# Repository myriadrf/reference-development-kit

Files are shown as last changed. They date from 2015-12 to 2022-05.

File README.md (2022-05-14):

# Myriad-RF Hardware

This repository contains the [Myriad-RF](http://myriadrf.org/) reference hardware designs for Lime Microsystem's LMS6002D and LMS7002M transceivers, plus LMS8001 up/down converter, in PDF and [KiCad](http://www.kicad.org) formats, along with the associated firmware.

## Contents

The directory structure for the hardware designs is as follows:

      docs/                      - platform documentation

      <project>/hardware/<version>/
          BOM/                   - bill of materials spreadsheet
          Gerbers/               - Gerber CAM files
          KiCAD/                 - KiCAD schematic and layout files
          Manufacturing/         - Additional manufacturing information
          PDF/                   - Schematic and layout PDFs
          Reports/               - DRC, ERC and drill reports

### Documentation

* RFDIO Connector Specification

The Myriad-RF Radio Frequency Digital Input Output (RFDIO) connector specification defines the electrical and mechanical properties of a high speed card interface for Field Programmable Gate Array (FPGA) based carrier boards. This specification ensures interoperability between carrier (mother) boards and add-on (daughter) RF cards.

*Please note that this needs to be updated with details of the connector specification used by the micro series of boards.*

### Myriad-RF 1 module (myriadrf-1)

Hardware design files for the LMS6002-based Myriad-RF 1 RF module.

Note that there are two versions of the design: one with vias in pads, and another with them off.

### DE0-Nano Interface (de0nano-interface)

Hardware design files and firmware sources (FPGA HDL + Cypress FX2 code) for the DE0-Nano interface that is used with the original Myriad-RF 1 module.

### Zipper Interface (zipper)

This interface allows the Myriad-RF 1 to be used with FPGA development boards that have either a HSMC or FMC connector.

*Note that v1 of the hardware design was not made generally available.*

### uMyriadRF-6002 (umyriadrf-6002)

LMS6002 version of the micro form factor RF module.

### uMyriadRF-7002 (umyriadrf-7002)

LMS7002 version of the micro form factor RF module.

### MyriadRF-8001 (myriadrf-8001)

LMS8001 Companion.

## Licensing

### Hardware

The hardware designs are licensed under a Creative Commons Attribution 3.0 Unported licence.

*Note: The Myriad-RF 1 and DE0-Nano Interface hardware designs were initially published under the Creative Commons Attribution-ShareAlike 3.0 Unported licence. As of 30th September 2013 these have been re-licensed under the more permissive Creative Commons Attribution 3.0 Unported licence.*

### Firmware

For details of firmware licensing please see the associated COPYING file(s).

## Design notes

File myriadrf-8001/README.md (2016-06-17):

# LMS8001 Companion

## Front

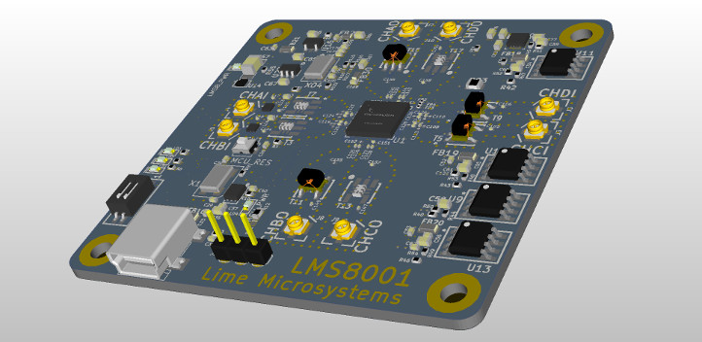
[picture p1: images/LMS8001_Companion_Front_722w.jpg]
LMS8001 Companion front


## Back

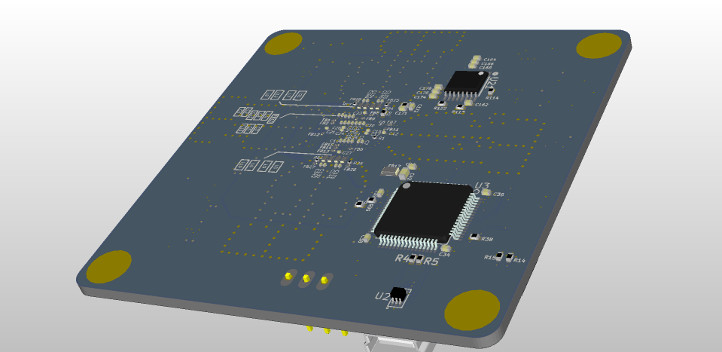
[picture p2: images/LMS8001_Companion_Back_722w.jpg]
LMS8001 Companion back


## Specifications

* Frequency range: 100kHz – 12GHz
* RF bandwidth: 120 MHz
* TRX configuration: MIMO
* Duplex: Full and half
* Power consumption: 1.5W

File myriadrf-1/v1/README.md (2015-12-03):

# Myriad-RF 1 RF Module version 1

## IMPORTANT!

Previous versions are retained for reference and are not intended for use in manufacturing.

## Changes

Note that r1 and r2 were interim updates and were not manufactured.

### 2014-03-03 r.3

Updated due to obsolete components.

Changed:

#### Schematics updates, pages "Clocks” and  “RF FE":

1. Component DA6 - Obsolete RF switch (PE4210) is changed, to new part PE42422
2. Added capacitor on TX Test track C26=100pF

#### PCB Layout updates

1. New footprint of PE42422 part
2. Rounded RF tracks
3. The GND and power supply vias mask closed (so there is no open vias on board)
4. The board annotation note "Board v.1 r.3" on the bottom layer silkscreen
5. The dimension lines (48 x 46 mm) on Drawings layer

#### BOM updates

1. Manufacturer of the capacitors is to KEMET: Capacitor values: 1.2pF, 1.8pF and 3.9pF
2. Included Board revision line
3. Changed dimensions to 48 x 46 mm
4. Included Drawings layout in list of gerber files
5. Included more report files in report folder

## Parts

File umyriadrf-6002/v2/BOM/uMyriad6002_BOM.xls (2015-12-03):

Component | QTY | Reference | Footprint | Supplier | Supplier Part Nr | Manufacturer | Manu Part Nr | Description | Assemble
1.0pF | 1 | C4 | C_SM0402 | Farnell | 1889196 | MURATA | GJM1555C1H1R0BB01D | CAPACITOR; NP0; 0402; 1PF;
8.2pF | 2 | C6 C8 | C_SM0402 | Farnell | 1865418 | KEMET | C0402C829C5GACTU | CAPACITOR; NP0; 0402; 50V; 8.2PF;
10pF | 1 | C22 | C_SM0402 | Farnell | 1709776 | MULTICOMP | MC0402N100F500CT | CAPACITOR CERAMIC 10PF 50V; C0G; 1%; 0402
33pF | 14 | C17 C37 C39 C42 C46 C48 C50 C51 C54 C56 C57 C61 C63 C65 | C_SM0402 | Farnell | 1856052 | MULTICOMP | MCCA000902 | CAPACITOR; 0402; NP0; 16V; 33PF;
100pF | 4 | C2 C3 C5 C7 | C_SM0402 | Farnell | 8819572 | MURATA | GRM1555C1H101JD01D | CAPACITOR; 0402; 100PF; 50V;
150pF | 2 | C11 C14 | C_SM0402 | Farnell | 1758976 | MULTICOMP | MCCA000122 | MLCC; 0402; NP0; 50V; 150PF;
470pF | 2 | C9 C12 | C_SM0402 | Farnell | 1758987 | MULTICOMP | MCCA000132 | MLCC; 0402; X7R; 50V; 470PF;
10nF | 2 | C10 C13 | C_SM0402 | Farnell | 3019275 | YAGEO (PHYCOMP) | CC0402KRX7R7BB103 | CAPACITOR; 0402; 10NF; 16V;
100nF | 17 | C1 C15 C16 C36 C38 C40 C41 C43 C45 C47 C49 C53 C55 C59 C62 C67 C111 | C_SM0402 | Farnell | 1288282 | KEMET | C0402C104K8PACTU | CAPACITOR; 0402; 100NF; 10V; X5R;
1uF | 5 | C60 C66 C68 C69 C204 | C_SM0402 | Farnell | 1759381 | MULTICOMP | MCCA000506 | MLCC; 0402; X5R; 10V; 1UF;
10uF | 2 | C52 C58 | C_SM0603 | Farnell | 2113070RL | TAIYO YUDEN | LMK107BJ106MALTD | CAPACITOR; 10UF; 10V; X5R; 0603;
LMS6002DR2 | 1 | DA1 | ~
SHIELD | 1 | EK1 | shield_21x21mm | Digi-Key | 732-2486-ND | Wurth Electronics Inc | 36103205 | BOARD SHIELD 20X20MM SMD FRAME
SHIELD | 1 | EK2 | shield_21x21mm | Digi-Key | 732-2486-ND | Wurth Electronics Inc | 36103205 | BOARD SHIELD 20X20MM SMD FRAME | NOFIT
100-PIN_CONNECTOR_1.5MMHEIGHT | 1 | J1 | 100-PIN_CONNECTOR | Digi-Key | H11615CT-ND | Hirose Electric Co Ltd | DF40C-100DS-0.4V(51) | CONN RCPT 100POS 0.4MM SMD GOLD
12nH NF | 1 | L3 | L_SM0402 | Coilcraft | 0402HP-12NX_LU | Coilcraft | 0402HP-12NX_LU | Inductor, 12 nH, 0402, 5%, | NOFIT
36nH | 2 | L1 L2 | L_SM0402 | Coilcraft | 0402CS-36NX_LU | Coilcraft | 0402CS-36NX_LU | Inductor; 36 nH; 0402; 5%;
LED | 1 | LD1 | LD0603 | Farnell | 1226372RL | OSRAM | LGQ971 | OSRAM - LGQ971 - LED; SMD; GREEN;
0R_0402 | 2 | R55 R63 | R_SM0402 | Digi-Key | 311-0.0JRCT-ND | Yageo | RC0402JR-070RL | RES, 0.0 OHM,1/16W, JUMP, 0402 SMD,
22 | 2 | R53 R57 | R_SM0402 | Farnell | 1117301 | YAGEO (PHYCOMP) | RC0402FR-0722RL | RESISTOR; 0402; 22R; 1%; REEL 10000;
47 | 4 | R22 R23 R24 R25 | R_SM0402 | Farnell | 1117311 | YAGEO (PHYCOMP) | RC0402FR-0747RL | RESISTOR; 0402; 47R; 1%; REEL 10000;
390 | 1 | R7 | R_SM0402 | Farnell | 9239189 | YAGEO (PHYCOMP) | RC0402FR-07390RL | RESISTOR; RC32H; 0402; 390R;
470 | 1 | R35 | R_SM0402 | Farnell | 9239197 | YAGEO (PHYCOMP) | RC0402FR-07470RL | RESISTOR; RC32H; 0402; 470R;
820 | 2 | R2 R5 | R_SM0402 | Farnell | 1358040RL | MULTICOMP | MC 0.0625W 0402 1% 820R | RESISTOR; 0402; 1%; 820R;
1K2 | 2 | R1 R3 | R_SM0402 | Farnell | 1358045 | MULTICOMP | MC 0.0625W 0402 1% 1K2 | RESISTOR; 0402; 1%; 1K2;
6K8 | 1 | R6 | R_SM0402 | Farnell | 1358064 | MULTICOMP | MC 0.0625W 0402 1% 6K8 | RESISTOR; 0402; 1%; 6K8;
10K_0402 | 3 | R11 R17 R21 | R_SM0402 | Digi-Key | 311-10.0KLRCT-ND | Yageo | RC0402FR-0710KL | RES 10K OHM 1/16W 1% 0402 SMD
12K | 1 | R4 | R_SM0402 | Farnell | 1358071RL | MULTICOMP | MC 0.0625W 0402 1% 12K | RESISTOR; 0402; 1%; 12K;
100MHz/600/0.2A | 15 | R41 R42 R43 R44 R46 R48 R50 R51 R52 R54 R56 R59 R60 R61 R62 | R_SM0402 | Farnell | 1961693 | WURTH ELEKTRONIK | 7427927161 | FERRITE BEAD; 600R; 0.25A; 0402;
SCREW | 1 | S1 | SCREW
TR_TCM1-63AX+ | 2 | T1 T2 | TCM1-63AX+ | Mini-Circuits | RF Transformer; 10 - 6000 MHz; RF Power 0.2 Watt; Ratio 1:1; 50 Ohm; | TCM1-63AX+ | TCM1-63AX+ | TCM1-63AX+
U.FL | 2 | X1 X2 | U.FL | Digi-Key | WM5587CT-ND | Molex Inc | 734120110 | CONN UMC RCPT STR 50 OHM SMD

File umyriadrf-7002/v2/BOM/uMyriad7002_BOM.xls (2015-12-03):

Component | QTY | Referene | Footprint | Supplier | Supplier Part Nr | Manufacturer | Manu Part Nr | Description | Assemble
0.5PF_0402_NF | 2 | C6 C41 | SMD0402 | DigiKey | 311-1001-1-ND | Yageo | CC0402CRNPO9BNR50 | CAP CER, 0.5PF, 50V, NPO, 0402, | NOFIT
4.7PF_0402 | 4 | C9 C10 C11 C12 | SMD0402 | DigiKey | 490-6244-1-ND | Murata Electronics North America | GRM1555C1H4R7BA01D | CAP CER 4.7PF 50V NP0 0402
1UF_0201 | 46 | C35 C47 C50 C51 C52 C53 C54 C55 C56 C57 C58 C59 C60 C61 C62 C63 C65 C66 C67 C68 C69 C111 C145 C154 C167 C173 C175 C195 C197 C204 C205 C206 C207 C208 C209 C210 C211 C212 C213 C214 C255 C283 C301 C302 C303 C304 | SM0201 | Digi-Key | 445-8008-1-ND | TDK Corporation | C0603X5R0J105M030BC | CAP CER 1UF 6.3V 20% X5R 0201
100NF_0402 | 10 | C1 C2 C16 C18 C38 C39 C220 C221 C233 C234 | SMD0402 | DigiKey | 311-1047-1-ND | Yageo | CC0402ZRY5V7BB104 | CAP, CER, 0.1UF, 16V, Y5V, 0402,
1PF_0402 | 6 | C3 C7 C32 C40 C42 C43 | SMD0402 | DigiKey | 445-4854-1-ND | TDK Corporation | C1005C0G1H010B050BA | CAP CER, 1PF, 50V, NP0, 0402,
1UF_0402 | 5 | C4 C8 C13 C14 C15 | SMD0402 | Digi-Key | 311-1377-1-ND | Yageo | CC0402ZRY5V5BB105 | CAP, CER, 1UF, 6.3V, Y5V, 0402,
10PF_0402 | 1 | C22 | SMD0402 | Digi-Key | 311-1014-1-ND | Yageo | CC0402JRNPO9BN100 | CAP, CER, 10PF, 50V, 5%, NPO, 0402,
100PF_0402 | 8 | C33 C45 C218 C219 C223 C231 C232 C236 | SMD0402 | Digi-Key | 311-1024-1-ND | Yageo | CC0402JRNPO9BN101 | CAP CER, 100PF, 50V, 5%, NPO, 0402,
22PF_0402 | 4 | C17 C19 C222 C235 | SMD0402 | DigiKey | 311-1018-1-ND | Yageo | CC0402JRNPO9BN220 | CAP CER, 22PF, 50V, 5%, NPO, 0402,
SHIELD_30X25MM | 1 | EK1 | shield_30x25mm
SHIELD_30X25MM | 1 | EK2 | shield_30x25mm |  |  |  |  |  | NOFIT
FB_0201 | 21 | FB1 FB2 FB3 FB4 FB5 FB6 FB7 FB8 FB9 FB10 FB11 FB12 FB13 FB14 FB15 FB16 FB17 FB18 FB19 FB22 FB24 | SM0201 | Digi-Key | 587-3277-1-ND | Taiyo Yuden | BK0603TS601-T | FERRITE BEAD 600 OHM 0201
FB_0201_NF | 2 | FB23 FB25 | SM0201 | Digi-Key | 587-3277-1-ND | Taiyo Yuden | BK0603TS601-T | FERRITE BEAD 600 OHM 0201 | NOFIT
100-PIN_CONNECTOR_3MMHEIGHT | 1 | J1 | 100-PIN_CONNECTOR | Digi-Key | H124602CT-ND | Hirose Electric Co Ltd | DF40HC(3.0)-100DS-0.4V(58) | CONN RCPT 100POS 0.4MM SMD GOLD
3.9NH_0402 | 2 | L4 L6 | IND_0402 | Coilcraft | 0402HP-3N9XGLU | Coilcraft | 0402HP-3N9XGLU | Inductor, 3.9 nH, 0402, 2%,
8.2NH_0402 | 4 | L7 L8 L12 L13 | IND_0402 | Coilcraft | 0402HP-8N2XJLU | Coilcraft | 0402HP-8N2XJLU | Inductor, 8.2 nH, 0402, 5%,
12NH_0402_NF | 4 | L3 L5 L9 L14 | IND_0402 | Coilcraft | 0402HP-12NX_LU | Coilcraft | 0402HP-12NX_LU | Inductor, 12 nH, 0402, 5%, | NOFIT
LED | 1 | LD1 | LED_0603 | Digi-Key | 475-1409-1-ND | OSRAM Opto Semiconductors Inc | LG Q971-KN-1 | LED, CHIPLED, 570NM, GREEN, 0603, SMD,
0R_0201 | 4 | R5 R6 R40 R43 | SMD0201 | Digi-Key | RHM0.0CCCT-ND | Rohm Semiconductor | MCR006YRTJ000 | RES 0.0 OHM 1/20W JUMP 0201 SMD
0R_0402 | 1 | R8 | SMD0402 | Digi-Key | 311-0.0JRCT-ND | Yageo | RC0402JR-070RL | RES, 0.0 OHM,1/16W, JUMP, 0402 SMD,
0R_0805 | 4 | R9 R12 R13 R14 | SM0805 | Digi-Key | 311-0.0ARCT-ND | Yageo | RC0805JR-070RL | RES SMD 0.0 OHM JUMPER 1/8W 0805
0.22R_0402 | 2 | R3 R4 | SMD0402 | Digi-Key | 311-.22PCT-ND | Yageo | RL0402FR-070R22L | RES SMD, 0.22 OHM, 1%, 1/16W, 0402,
10R_0201 | 6 | R7 R17 R23 R33 R41 R42 | SMD0201 | Digi-Key | YAG1245CT-ND | Yageo | RC0201JR-0710RP | RES SMD, 10 OHM, 5%, 1/20W, 0201,
47R_0402 | 4 | R25 R26 R27 R28 | SMD0402 | Digi-Key | 311-47.0LRCT-ND | Yageo | RC0402FR-0747RL | RES, 47 OHM, 1/16W, 1%, 0402, SMD,
470R_0402 | 1 | R10 | SMD0402 | Digi-Key | P470DECT-ND | Panasonic Electronic Components | ERA-2AED471X | RES, 470 OHM, 1/16W, .5%, 0402 SMD,
2K2_0402 | 2 | R29 R39 | SMD0402 | Digi-Key | 311-2.20KLRCT-ND | Yageo | RC0402FR-072K2L | RES, 2.20K OHM, 1/16W, 1%, 0402, SMD,
10K_0402 | 10 | R1 R2 R11 R19 R20 R21 R22 R24 R44 R45 | SMD0402 | Digi-Key | RMCF0402FT10K0CT-ND | Stackpole Electronics Inc | RMCF0402FT10K0 | RES 10K OHM 1/16W 1% 0402
TR_TC1 | 2 | T5 T6 | TC1-1-13MA+ | Municom | TC1-1-13MA+ | Mini-Circuits | TC1-1-13MA+ | RF Transformer, 4.5 - 3000 MHz, RF Power 0.25 Watt, Ratio 1:1, 50 Ohm,
TR_TCM1-63AX+ | 4 | T1 T2 T3 T4 | TCM1-63AX+ | Mini-Circuits | RF Transformer; 10 - 6000 MHz; RF Power 0.2 Watt; Ratio 1:1; 50 Ohm; | TCM1-63AX+ | TCM1-63AX+ | TCM1-63AX+
PE4245 | 2 | U7 U9 | 6-DFN_PE4245 | Digi-Key | 1046-1024-1-ND | Peregrine Semiconductor | 4245-52 | IC RF SWITCH SPDT 50 OHM 6-DFN
LD39115J14R | 1 | U2 | 4-UFBGA | Digi-Key | 497-15591-1-ND | STMicroelectronics | LD39115J14R | IC REG LDO 1.4V 0.15A 4FLIPCHIP
24FC512 | 1 | U6 | 8-TSSOP | Digi-Key | 24FC512-I/ST-ND | Microchip Technology | 24FC512-I/ST | IC EEPROM 512KBIT 1MHZ 8TSSOP
24FC64F | 1 | U8 | 8-TSSOP | Digi-Key | 24FC64F-I/ST-ND | Microchip Technology | 24FC64F-I/ST | IC EEPROM 64KBIT 1MHZ 8TSSOP
LMS7002 | 1 | U1 | aQFN-261
U.FL | 4 | X1 X2 X3 X4 | U.FL | Digi-Key | WM5587CT-ND | Molex Inc | 734120110 | CONN UMC RCPT STR 50 OHM SMD

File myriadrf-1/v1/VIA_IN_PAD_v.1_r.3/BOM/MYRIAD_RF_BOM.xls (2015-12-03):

VALUE | QTY | Reference | Footprint | Description | Manufacturer Part Number | Manufacturer | Vendor | Vendor Part Number | Assemble
0.5pF | 2 | C33 C120 | C_SM0402 | CAP; CER; 0.5PF; 50V; NPO; 0402; | CC0402CRNPO9BNR50 | Yageo | Digi-Key | 311-1001-2-ND
1.0pF | 3 | C21 C34 C72 | C_SM0402 | CAPACITOR; NP0; 0402; 1PF; | GJM1555C1H1R0BB01D | MURATA | Farnell | 1889196
1.2pF | 3 | C36 C44 C49 | C_SM0402 | CAP; CER; 1.2PF; 100V; NP0; 0402; | CBR04C129B1GAC | KEMET | Digi-Key | 399-8598-1-ND
1.8pF | 3 | C91 C92 C93 | C_SM0402 | CAP; CER; 1.8PF; 100V; NP0; 0402; | CBR04C189B1GAC | KEMET | Digi-Key | 399-8596-1-ND
3.9pF | 2 | C94 C95 | C_SM0402 | CAP; CER; 3.9PF; 100V; NP0; 0402; | CBR04C399B1GAC | KEMET | Digi-Key | 399-8588-1-ND
8.2pF | 2 | C31 C68 | C_SM0402 | CAPACITOR; NP0; 0402; 50V; 8.2PF; | C0402C829C5GACTU | KEMET | Farnell | 1865418
10pF | 1 | C221 | C_SM0402 | CAPACITOR CERAMIC 10PF 50V; C0G; 1%; 0402 | MC0402N100F500CT | MULTICOMP | Farnell | 1709776
33pF | 13 | C53 C55 C73 C78 C105 C106 C109 C110 C111 C112 C113 C114 C115 | C_SM0402 | CAPACITOR; 0402; NP0; 16V; 33PF; | MCCA000902 | MULTICOMP | Farnell | 1856052
100pF | 13 | C26 C27 C51 C54 C56 C57 C59 C60 C61 C63 C69 C77 C101 | C_SM0402 | CAPACITOR; 0402; 100PF; 50V; | GRM1555C1H101JD01D | MURATA | Farnell | 8819572
150pF | 2 | C15 C18 | C_SM0402 | MLCC; 0402; NP0; 50V; 150PF; | MCCA000122 | MULTICOMP | Farnell | 1758976
470pF | 2 | C13 C16 | C_SM0402 | MLCC; 0402; X7R; 50V; 470PF; | MCCA000132 | MULTICOMP | Farnell | 1758987
10nF | 4 | C14 C17 C25 C136 | C_SM0402 | CAPACITOR; 0402; 10NF; 16V; | CC0402KRX7R7BB103 | YAGEO (PHYCOMP) | Farnell | 3019275
100nF | 23 | C3 C4 C7...C12 C19 C35 C74...C76 C82 C84 C85 C90 C216...C220 C224 | C_SM0402 | CAPACITOR; 0402; 100NF; 10V; X5R; | C0402C104K8PACTU | KEMET | Farnell | 1288282
1uF | 5 | C1 C2 C5 C6 C20 | C_SM0402 | MLCC; 0402; X5R; 10V; 1UF; | MCCA000506 | MULTICOMP | Farnell | 1759381
1uF | 6 | C22 C23 C81 C88 C122 C144 | C_SM0603 | CAPACITOR; 0603; 1UF; 10V; X5R; 10%; | CC0603KRX5R6BB105 | YAGEO (PHYCOMP) | Farnell | 9402080
2.2uF | 2 | C24 C117 | C_SM0603 | CAPACITOR; 0603; X5R; 10V; 2.2UF; | GRM188R61A225KE34D | MURATA | Farnell | 1828799
10uF | 4 | C52 C83 C222 C223 | C_S0603 | CAPACITOR; 10UF; 10V; X5R; 0603; | LMK107BJ106MALTD | TAIYO YUDEN | Farnell | 2113070RL
LD1117DT33 | 1 | DA1 | DPAK2 | LD1117DT33 - V REG LDO +3.3V; SMD; 1117; DPAK-3 | LD1117DT33 | STMICROELECTRONICS | Farnell | 1087169
LMS6002DR2 | 1 | DA3 | DQFN-120 | LMS6002 Tranceiver; DQFN-120; | LMS6002DR2 | Lime Microsystems | Lime Microsystems | LMS6002DR2
PE42440 | 1 | DA5 | QFN-16 | IC RF SWITCH; SP4T; 50 OHM; 16QFN; | PE42440 | Peregrine Semiconductor | Digi-Key | 1046-1038-1-ND
PE42422 | 1 | DA6 | QFN12 | IC; RF SWITCH; SPDT; 50 OHM; 12QFN; | PE42422MLAA-Z | Peregrine Semiconductor | Digi-Key | 1046-1062-1-ND
LP2985IM5-1.8 | 2 | DA2 DA7 | SOT23-5 | LP2985IM5-1.8/NOPB - IC; REG; LDO; 1.8V; 150MA; SOT23 | LP2985IM5-1.8/NOPB | NATIONAL SEMICONDUCTOR | Farnell | 1564761RL
CDCV304PW | 1 | DA4 | TSSOP-8 | CDCV304PWR - IC; CLOCK BUFFER; | CDCV304PWR | TEXAS INSTRUMENTS | Farnell | 1703244
Shield | 1 | EK1 | EK | EMI Gaskets & Earth Pads 204 Frame | BMI-S-204-F | Laird Technologies | Mouser | 739-BMIS-204-F | NOFIT
4.7nH | 4 | L17 L22 L34 L35 | L_SM0402 | Inductor; 4.7 nH; 0402; 5%; | 0402HP-4N7X_LU | Coilcraft | Coilcraft | 0402HP-4N7X_LU
5.6nH | 3 | L27 L28 L29 | L_SM0402 | Inductor; 5.6 nH; 0402; 5%; | 0402HP-5N6XJLU | Coilcraft | Coilcraft | 0402HP-5N6XJLU
12nH | 3 | L32 L36 L37 | L_SM0402 | Inductor; 12 nH; 0402; 5%; | 0402HP-12NX_LU | Coilcraft | Coilcraft | 0402HP-12NX_LU
12nH | 2 | L38 L40 | L_SM0402 | Inductor; 12 nH; 0402; 5%; | 0402HP-12NX_LU | Coilcraft | Coilcraft | 0402HP-12NX_LU | NOFIT
15nH | 1 | L26 | L_SM0402 | Inductor; 15 nH; 0402; 5%; | 0402HP-15NX_LU | Coilcraft | 0402HP-15NX_LU | Coilcraft
22nH | 1 | L42 | L_SM0402 | Inductor; 22 nH; 0402; 5%; | 0402HP-22NX_LU | Coilcraft | Coilcraft | 0402HP-22NX_LU
36nH | 4 | L11 L12 L13 L33 | L_SM0402 | Inductor; 36 nH; 0402; 5%; | 0402CS-36NX_LU | Coilcraft | Coilcraft | 0402CS-36NX_LU
LED | 1 | LD1 | LD0603 | OSRAM - LGQ971 - LED; SMD; GREEN; | LGQ971 | OSRAM | Farnell | 1226372RL
0 | 13 | R4 R12 R18 R23 R24 R25 R28 R42 R44 R46 R92 R139 R164 | R_SM0402 | RESISTOR; 0402; 0R; REEL 10000; | RC0402JR-070RL | YAGEO (PHYCOMP) | Farnell | 1117280
0 | 5 | R26 R27 R29 R49 R153 | R_SM0402 | RESISTOR; 0402; 0R; REEL 10000; | RC0402JR-070RL | YAGEO (PHYCOMP) | Farnell | 1117280 | NOFIT
0 | 2 | R1 R82 | R_SM0805 | RESISTOR; RC11; 0805; 0R; | RC0805JR-070RL | YAGEO (PHYCOMP) | Farnell | 9233750
0 | 1 | R5 | R_SM0805 | RESISTOR; RC11; 0805; 0R; | RC0805JR-070RL | YAGEO (PHYCOMP) | Farnell | 9233750 | NOFIT
22 | 7 | R16 R17 R38 R39 R45 R47 R48 | R_array | RESISTOR ARRAY; ARV341; 0804; 22R; | YC124-JR-0722RL | YAGEO (PHYCOMP) | Farnell | 9235264
22 | 2 | R74 R75 | R_SM0402 | RESISTOR; 0402; 22R; 1%; REEL 10000; | RC0402FR-0722RL | YAGEO (PHYCOMP) | Farnell | 1117301
47 | 5 | R130 R131 R132 R133 R134 | R_SM0402 | RESISTOR; 0402; 47R; 1%; REEL 10000; | RC0402FR-0747RL | YAGEO (PHYCOMP) | Farnell | 1117311
49.9 | 1 | R69 | R_SM0402 | RESISTOR; 0402; 1%; 49R9; | MC 0.0625W 0402 1% 49R9 | MULTICOMP | Farnell | 1802906RL
51 | 4 | R59 R60 R63 R64 | R_SM0402 | RESISTOR; 0402; 0.063W; 1%; 51R; | RC0402FR-0751RL | YAGEO (PHYCOMP) | Farnell | 1458803RL
390 | 1 | R35 | R_SM0402 | RESISTOR; RC32H; 0402; 390R; | RC0402FR-07390RL | YAGEO (PHYCOMP) | Farnell | 9239189
470 | 1 | R43 | R_SM0402 | RESISTOR; RC32H; 0402; 470R; | RC0402FR-07470RL | YAGEO (PHYCOMP) | Farnell | 9239197
820 | 2 | R31 R33 | R_SM0402 | RESISTOR; 0402; 1%; 820R; | MC 0.0625W 0402 1% 820R | MULTICOMP | Farnell | 1358040RL
1K2 | 2 | R30 R32 | R_SM0402 | RESISTOR; 0402; 1%; 1K2; | MC 0.0625W 0402 1% 1K2 | MULTICOMP | Farnell | 1358045
6K8 | 1 | R36 | R_SM0402 | RESISTOR; 0402; 1%; 6K8; | MC 0.0625W 0402 1% 6K8 | MULTICOMP | Farnell | 1358064
10K | 3 | R83 R84 R85 | R_SM0402 | RESISTOR; THICK FILM; 10KOHM; 62.5mW; 1%; | RC0402FR-1310KL | YAGEO | Farnell | 1799235
10K | 4 | R94 R95 R96 R98 | R_SM0402 | RESISTOR; THICK FILM; 10KOHM; 62.5mW; 1%; | RC0402FR-1310KL | YAGEO | Farnell | 1799235 | NOFIT
12K | 1 | R34 | R_SM0402 | RESISTOR; 0402; 1%; 12K; | MC 0.0625W 0402 1% 12K | MULTICOMP | Farnell | 1358071RL
1M | 3 | R2 R3 R50 | R_SM0402 | RESISTOR; THICK FILM; 1MOHM; 62.5mW; 1%; | RC0402FR-071ML | YAGEO | Farnell | 2127667
100MHz/600/0.2A | 16 | R6…R11 R13...R15 R19…R22 R37 R40 R87 | R_SM0402 | FERRITE BEAD; 600R; 0.25A; 0402; | 7427927161 | WURTH ELEKTRONIK | Farnell | 1961693
100MHz/60/1A | 3 | R41 R211 R215 | R_SM0805 | FERRITE BEAD; 0805; 60 OHM; | MMZ2012Y600B | TDK | Farnell | 1669733
TC1-1-13MA+ | 1 | T1 | TC1-1-13MA+ | RF Transformer; 4.5 - 3000 MHz; RF Power 0.25 Watt; Ratio 1:1; 50 Ohm; | TC1-1-13MA+ | Mini-Circuits | Municom | TC1-1-13MA+
TC4-25X+ | 1 | T2 | TC1-1-13MA+ | RF Transformer; 500 - 2500 MHz; RF Power 0.25 Watt; Ratio 1:4; 50 Ohm; | TC4-25X+ | Mini-Circuits | Municom | TC4-25X+
CONN_HROSE_FX10A-80P8 | 1 | X3 | FX10A-80P8 | CONN HEADER 80POS W/O POST SMD | FX10B-80P/8-SV1(71) | Hirose Electric | Digi-Key | H11228-ND
MMCX8400-0000 | 1 | X8 | MMCX | CON:MMCX Jack PCB Mount 50 Ohm | MMCX8400-0000 | JYEBAO | East Coast Microwave Dist | East Coast Microwave Dist
5-146285-2 | 1 | X2 | pinhead2 | BOARD-BOARD CONNECTOR HEADER; 2WAY; 1ROW; | 5-146285-2 | TE CONNECTIVITY / AMP | Farnell | 1341684
CONN_6 | 1 | X9 | pinhead6 | Headers & Wire Housings 06 MODII HDR SRST B/A W/HD; | 104345-4 | TE Connectivity | TTI | 104345-4
SMA8401-0000 | 2 | X6 X7 | SMA | SMA Female JACK PCB MOUNT 50Ohm; | SMA8401-0000 | JYEBAO | 100Y | 50192
5-104348-3 | 2 | X4 X5 | VR_pinhead5 | .100 inch AMPMODU Headers; RIGHT ANGLE; 5WAY; | 5-104348-3 | TE Connectivity | TTI | 5-104348-3

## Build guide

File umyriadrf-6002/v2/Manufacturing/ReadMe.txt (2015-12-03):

Board Description
-----------------

board designation           : uMyriadRF6002
board version		    : v2	
board type                  : Lead Free
board size                  : 49.3 mm x 36.6 mm
board thickness             : 
board material              : IT-180A
number of layers            : 8

Top layer copper foil thickness: 17.5 um
Dielectric thickness between Top layer and 2nd: 173 um (6.8 mils)
Dielectric between Top layer and 2nd relative permittivity (Er): 4.2

minimum finished hole size  :  200 um
minimum spacing             :  100 um
minimum track width         :  100 um

drill diameters             : finished hole

plating finish (both sides) : immersion gold
                              0.05-0.10 um of gold over
                              2.50-5.00 um of nickel

Important Notes
---------------

DRCs must be run on Gerber files before building boards.

All through hole vias may be plated shut.

Solder mask : black, both sides.

Silkscreen : white epoxy ink, both sides.

Electrical test : 100 % netlist.

Boards are to be individually bagged.

Design software used:  KiCad

Controlled Impedance
--------------------
  * 50 ohm microstrip line (Top layer) track width 0.33 mm

Board Stackup
----------------

 Solder Paste Front		: Stream-F_Paste.gtp
 Silk Screen Front		: Stream-F_SilkS.gto
 SolderMask Front		: Stream-F_Mask.gts

1. Front Layer			: Stream-F_Cu.gtl
2. Inner 6		        : Stream-Inner6_Cu.gbr
3. Inner 5	                : Stream-Inner5_Cu.gbr
4. Inner 4                      : Stream-Inner4_Cu.gbr
5. Inner 3                      : Stream-Inner3_Cu.gbr
6. Inner 2                      : Stream-Inner2_Cu.gbr
7. Inner 1                      : Stream-Inner1_Cu.gbr																
8. Back Layer			: Stream-B_Cu.gbl

 SolderMask Back		: Stream-B_Mask.gbs
 Silk Screen Back		: Stream-B_SilkS.gbo
 Solder Paste Back      	: Stream-B_Paste.gbp

--------------------------------------------------
 PCB edges           	: Stream-Edge_Cuts.gbr

 Drill map            	: Stream-drl_map.pho
         	 	: Stream-NPTH-drl_map.pho

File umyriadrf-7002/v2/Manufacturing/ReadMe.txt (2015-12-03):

Board Description
-----------------

board designation           : uMyriadRF7002
board version		    : v2	
board type                  : Lead Free
board size                  : 59.3 mm x 41.4 mm
board thickness             : 0.7 mm
board material              : IT-180A
number of layers            : 8

Top layer copper foil thickness: 17.5 um
Dielectric thickness between Top layer and 2nd, Bottom and 7th layers: 173 um (6.8 mils)
Dielectric between Top layer and 2nd, Bottom and 7th layers relative permittivity (Er): 4.2

minimum finished hole size  :  200 um
minimum spacing             :  100 um
minimum track width         :  100 um

drill diameters             : finished hole

plating finish (both sides) : immersion gold
                              0.05-0.10 um of gold over
                              2.50-5.00 um of nickel

Important Notes
---------------

DRCs must be run on Gerber files before building boards.

All through hole vias may be plated shut.

Solder mask : black, both sides.

Silkscreen : white epoxy ink, both sides.

Electrical test : 100 % netlist.

Boards are to be individually bagged.

Design software used:  KiCad

Controlled Impedance
--------------------
  * 50 ohm microstrip line (Top and Bottom layers) track width 0.33 mm

Board Stackup
----------------

 Solder Paste Front		: Stream-F_Paste.gtp
 Silk Screen Front		: Stream-F_SilkS.gto
 SolderMask Front		: Stream-F_Mask.gts

1. Front Layer			: Stream-F_Cu.gtl
2. Inner 6		        : Stream-Inner6_Cu.gbr
3. Inner 5	                : Stream-Inner5_Cu.gbr
4. Inner 4                      : Stream-Inner4_Cu.gbr
5. Inner 3                      : Stream-Inner3_Cu.gbr
6. Inner 2                      : Stream-Inner2_Cu.gbr
7. Inner 1                      : Stream-Inner1_Cu.gbr																
8. Back Layer			: Stream-B_Cu.gbl

 SolderMask Back		: Stream-B_Mask.gbs
 Silk Screen Back		: Stream-B_SilkS.gbo
 Solder Paste Back      	: Stream-B_Paste.gbp

--------------------------------------------------
 PCB edges           	: Stream-Edge_Cuts.gbr

 Drill map            	: Stream-drl_map.pho
         	 	: Stream-NPTH-drl_map.pho

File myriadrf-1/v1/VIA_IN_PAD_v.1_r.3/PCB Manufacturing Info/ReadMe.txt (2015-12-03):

Board Description
-----------------

board designation           : MYRIAD RF Via In-Pad 
board version		    : version 1, revision 3	
board type                  : Lead Free
board size                  : 48.0 mm x 46.0 mm
board thickness             : 1.6 mm +/- 10 %
board material              : FR4
number of layers            : 6

Top layer copper foil thickness: 17.5 um
Dielectric thickness between Top layer and 2nd layer: 173 um (6.8 mils)
Dielectric between Top layer and 2nd layer relative permittivity (Er): 4.2

minimum finished hole size  :  200 um
minimum spacing             :  100 um
minimum track width         :  100 um

Gerber file format          : RS-274-X 

drill diameters             : finished hole

plating finish (both sides) : immersion gold
                              0.08-0.20 um of gold over
                              2.50-5.00 um of nickel

edge connector plating      : 1.27 um hard gold over 1.27 um nickel

Important Notes
---------------

DRCs must be run on Gerber files before building boards.

All through hole vias may be plated shut.

Solder mask : black TAIYO, both sides, halogen free.

Silkscreen : white epoxy ink, halogen free, both sides.

Electrical test : 100 % netlist.

Boards are to be individually bagged.

Basic grid increment is 5 um.

Design software used:  KiCad

Controlled Impedance
--------------------

  * 50 Ohm coated single ended microstrip (Top layer)
    FR4, 6.8 mil, Er = 4.2, tand = 0.025, metal thickness 17.5 um
    track width 310 um

Board Stackup
----------------

1. Solder Paste Front		: MYRIAD_RF-SoldP_Front.gtp
2. Silk Screen Front		: MYRIAD_RF-SilkS_Front.gto
3. SolderMask Front		: MYRIAD_RF-Mask_Front.gts

4. Front Layer			: MYRIAD_RF-Front.gtl
5. Inner GND Layer		: MYRIAD_RF-Inner_GND.gbr																	
6. Inner Analog Signal Layer	: MYRIAD_RF-Inner_Analog_Signal.gbr
7. Inner Power Layer		: MYRIAD_RF-Inner_Power.gbr
8. Inner Digital Signal Layer	: MYRIAD_RF-Inner_Digital_Signal.gbr
9. Back Layer			: MYRIAD_RF-Back.gbl

10. SolderMask Back		: MYRIAD_RF-Mask_Back.gbs
11. Silk Screen Back		: MYRIAD_RF-SilkS_Back.gbo
12. Solder Paste Back      	: MYRIAD_RF-SoldP_Back.gbp

--------------------------------------------------
13. PCB edges           	: MYRIAD_RF-PCB_Edges.gbr
14. Drawings			: MYRIAD_RF-Dwgs_User.gbr

15. Drill map            	: MYRIAD_RF-drl.pho
16. NC Drill file	 	: MYRIAD_RF.drl

Reports folder
--------------
                  
MYRIAD_RF_erc.txt
MYRIAD_RF_drc.txt
MYRIAD_RF-drl.rpt.txt
MYRIAD_RF_all_models.txt

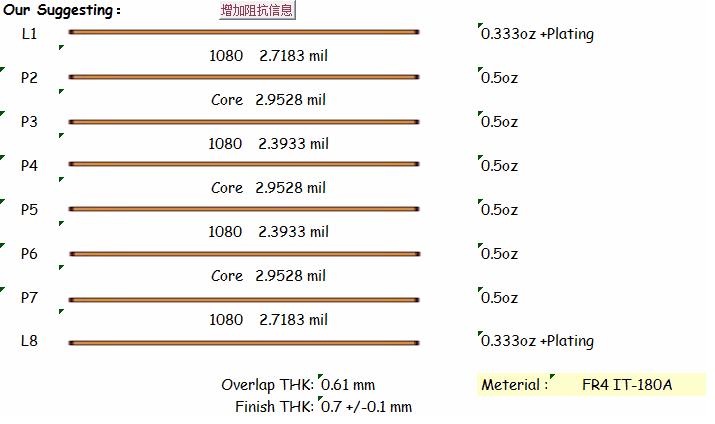
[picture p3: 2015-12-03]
umyriadrf-6002/v2/Manufacturing/stackup.jpg

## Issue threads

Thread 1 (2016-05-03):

bad KiCAD files

AnttiLukats, 2016-05-03:
umyriadrf-6002
umyriadrf-7002

the KiCAD PCB files can not be opened, there comes an error about missing layer and the PCB remains empty

championlee, 2016-05-03:
You need to use Kicad old stable version BZR4022 to open them. This version is still can be downloaded in http://kicad-pcb.org/download/windows/

AnttiLukats, 2016-05-04:
would it not be better to FIX the pcb files? the other kicad files can be opened, only those 2 not

championlee, 2016-05-04:
Although they are based BZR4022, I've tried still can be open without problem on latest stable version 4.0.2. Maybe you can check again on the right panel of PCBNEW to see whether the visibility checkbox for "missing layer" on layer page, and whether something (Pads, FootPrints, Text for Front/Back) are not selected on Render page.

championlee, 2016-05-04:
Some people believe Kicad 4.0.x are still unstable or not function well. That's why these designs are still using old stable version.

Closed 2016-05-07.

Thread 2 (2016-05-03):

incomplete BOM

AnttiLukats, 2016-05-03:
the connector type for the uStream is not given

championlee, 2016-05-03:
uStream J7 is DF40C-100DP-0.4V(51) from Hirose.

AnttiLukats, 2016-05-04:
Thank you, it looked like DF40, we are already using several DF40 family connectors.

Closed 2016-05-04.

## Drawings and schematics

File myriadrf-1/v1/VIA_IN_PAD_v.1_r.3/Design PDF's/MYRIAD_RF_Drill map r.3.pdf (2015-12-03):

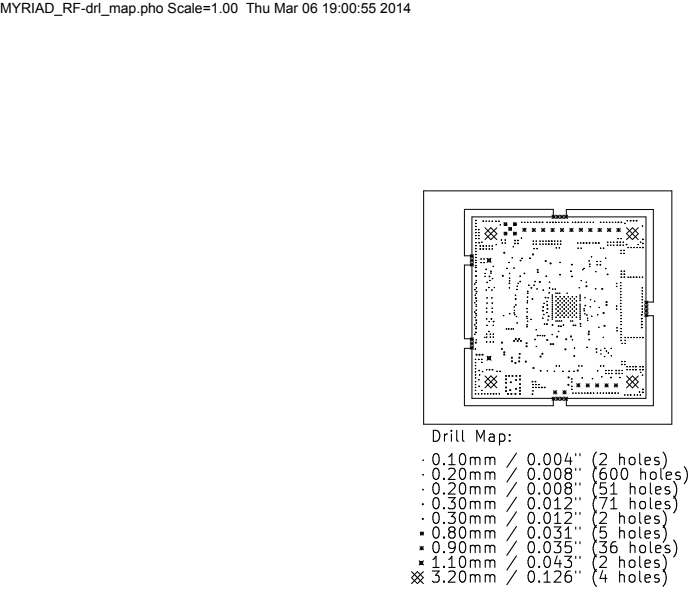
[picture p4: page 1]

MYRIAD_RF-drl_map.pho Scale=1.00 Thu Mar 06 19:00:55 2014

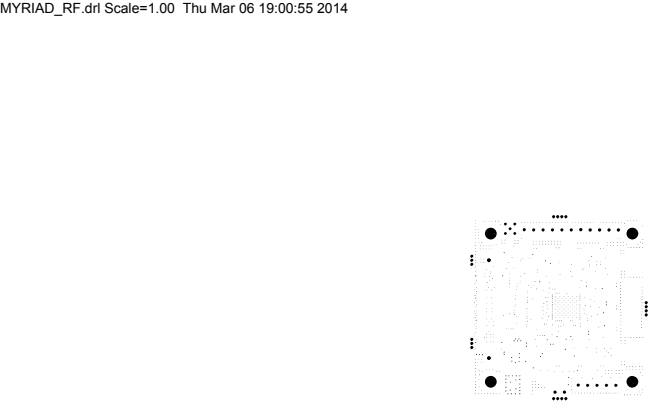
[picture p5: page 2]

MYRIAD_RF.drl Scale=1.00 Thu Mar 06 19:00:55 2014

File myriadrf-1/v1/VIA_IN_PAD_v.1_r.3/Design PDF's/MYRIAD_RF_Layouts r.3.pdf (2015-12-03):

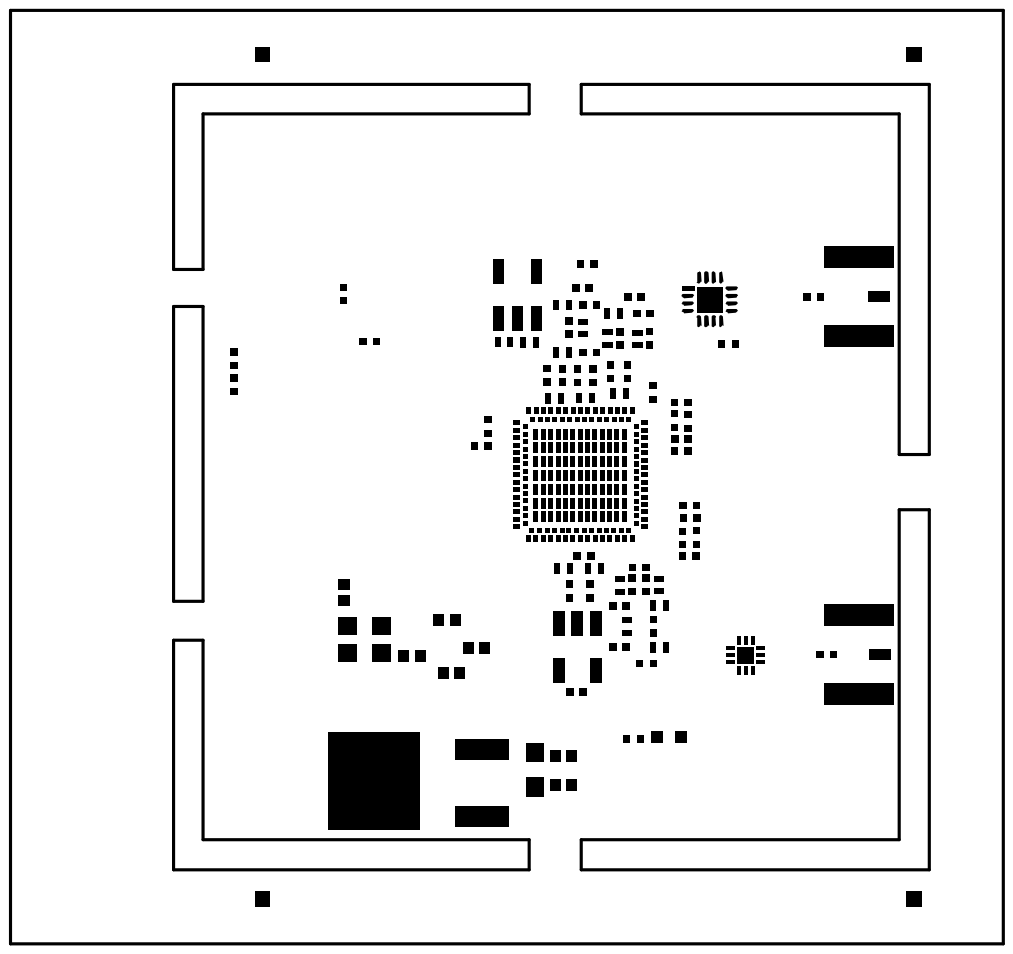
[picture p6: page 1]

MYRIAD_RF-F_Paste.gtp Scale=1.00 Thu Mar 06 18:58:20 2014

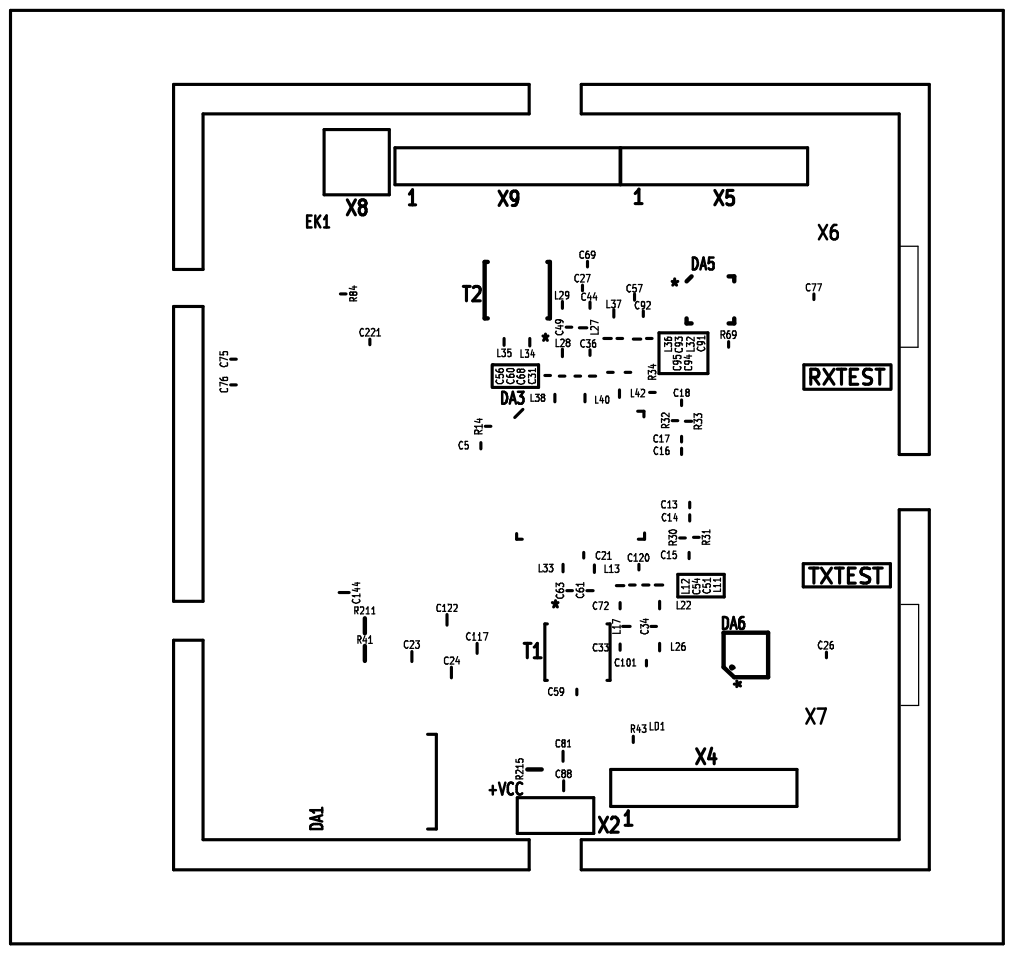
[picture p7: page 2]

MYRIAD_RF-F_SilkS.gto Scale=1.00 Thu Mar 06 18:58:20 2014

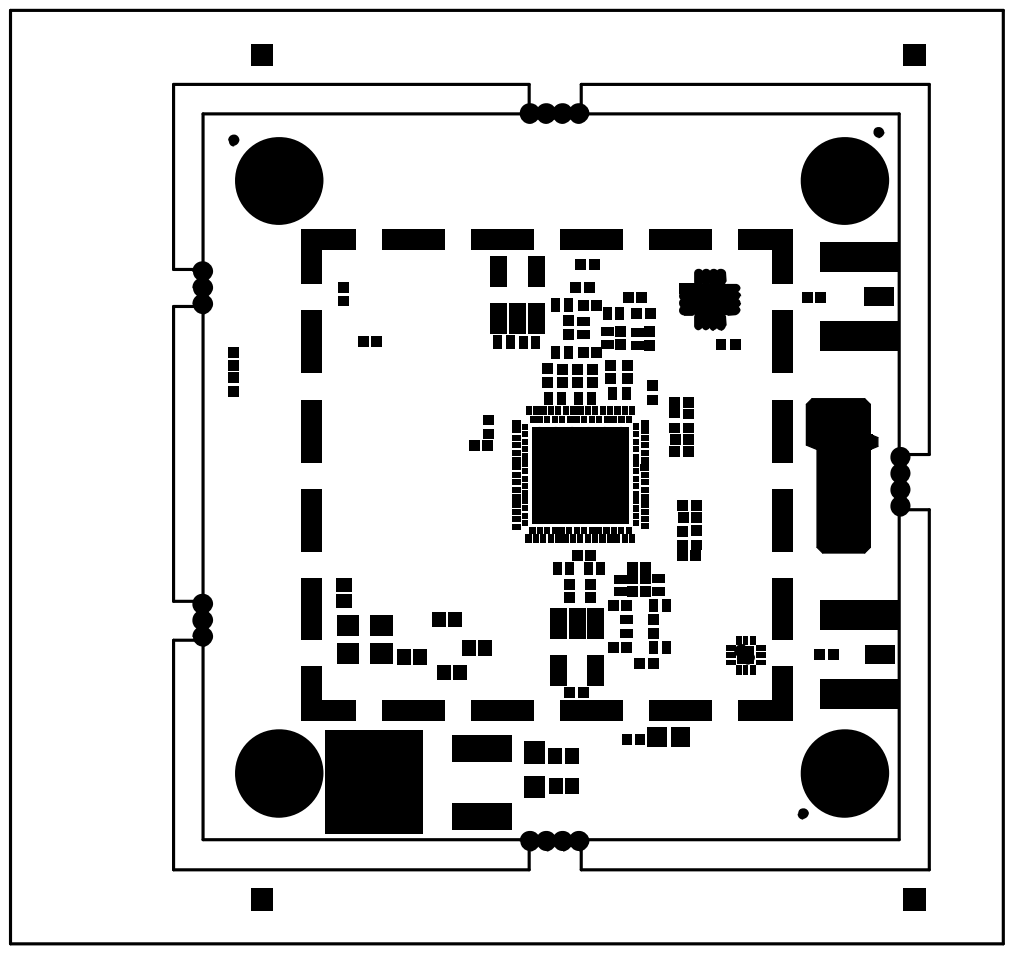
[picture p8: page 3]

MYRIAD_RF-F_Mask.gts Scale=1.00 Thu Mar 06 18:58:20 2014

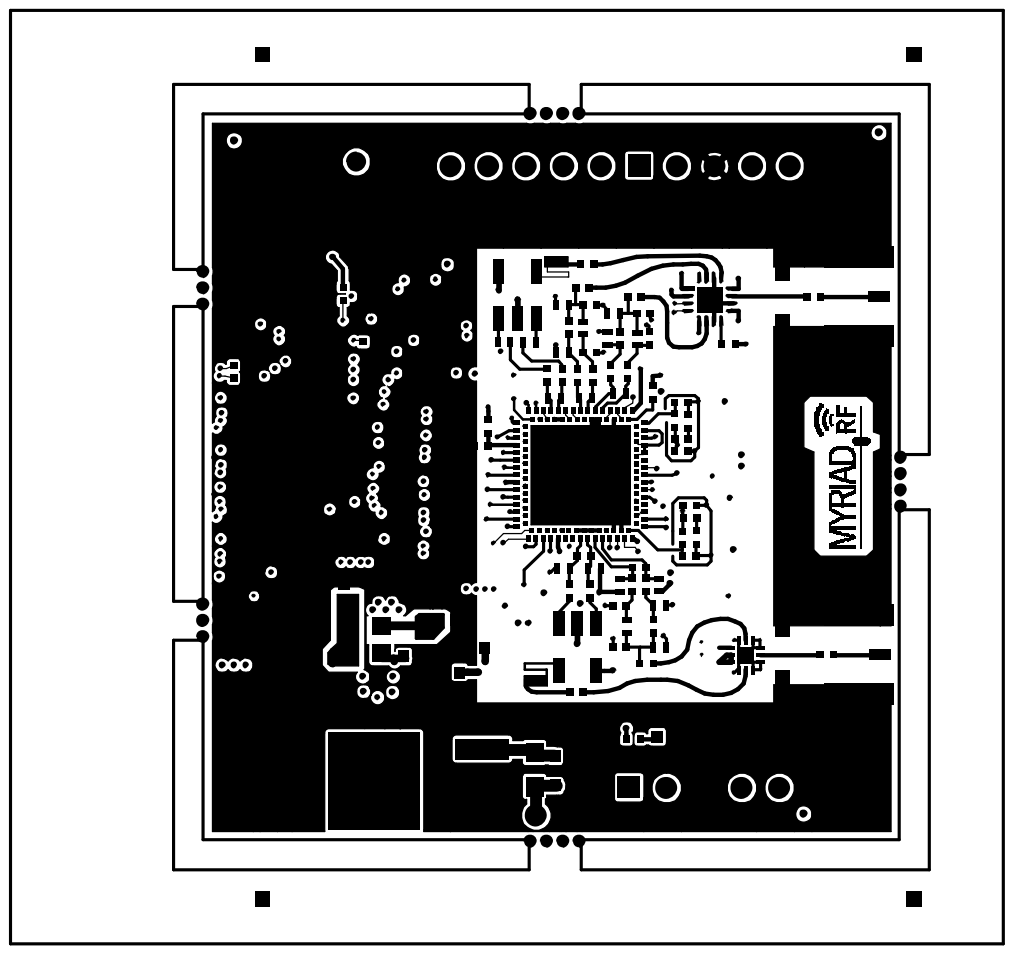
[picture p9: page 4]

MYRIAD_RF-Front.gtl Scale=1.00 Thu Mar 06 18:58:20 2014

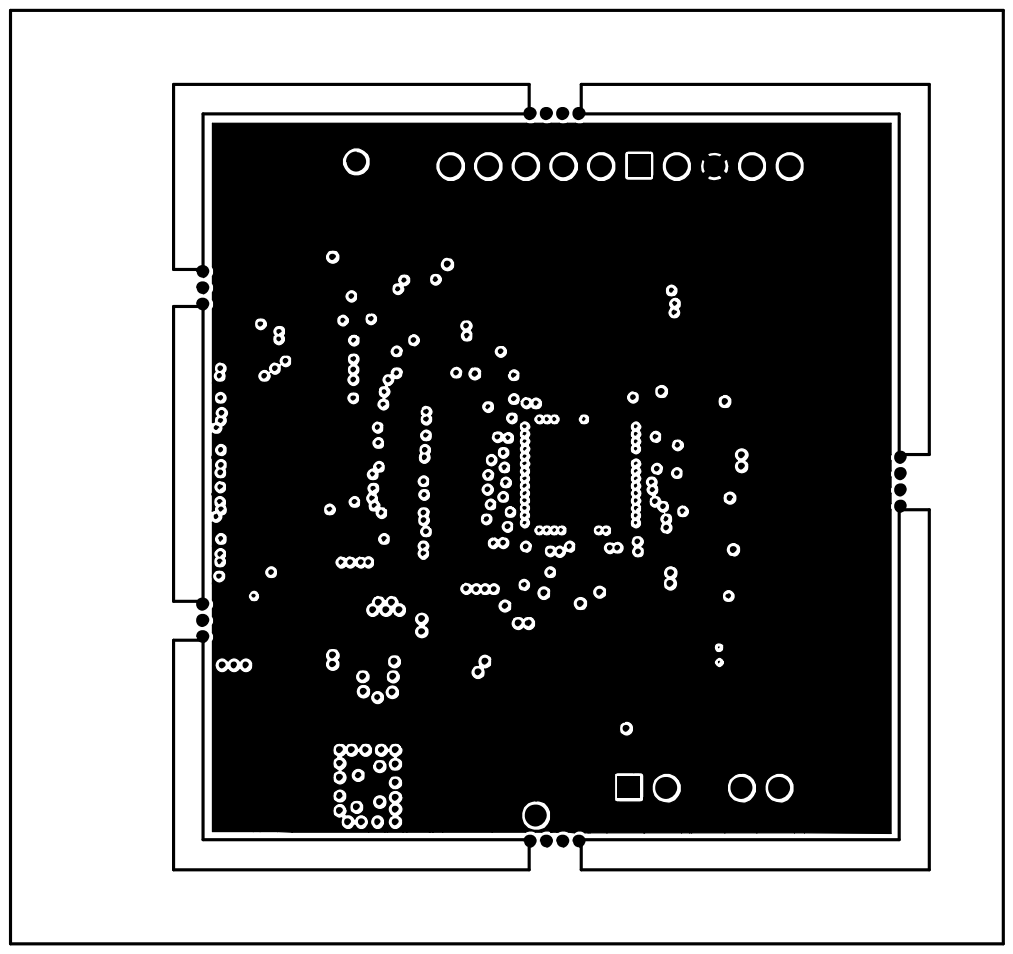
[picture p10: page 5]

MYRIAD_RF-Inner_GND.gbr Scale=1.00 Thu Mar 06 18:58:20 2014

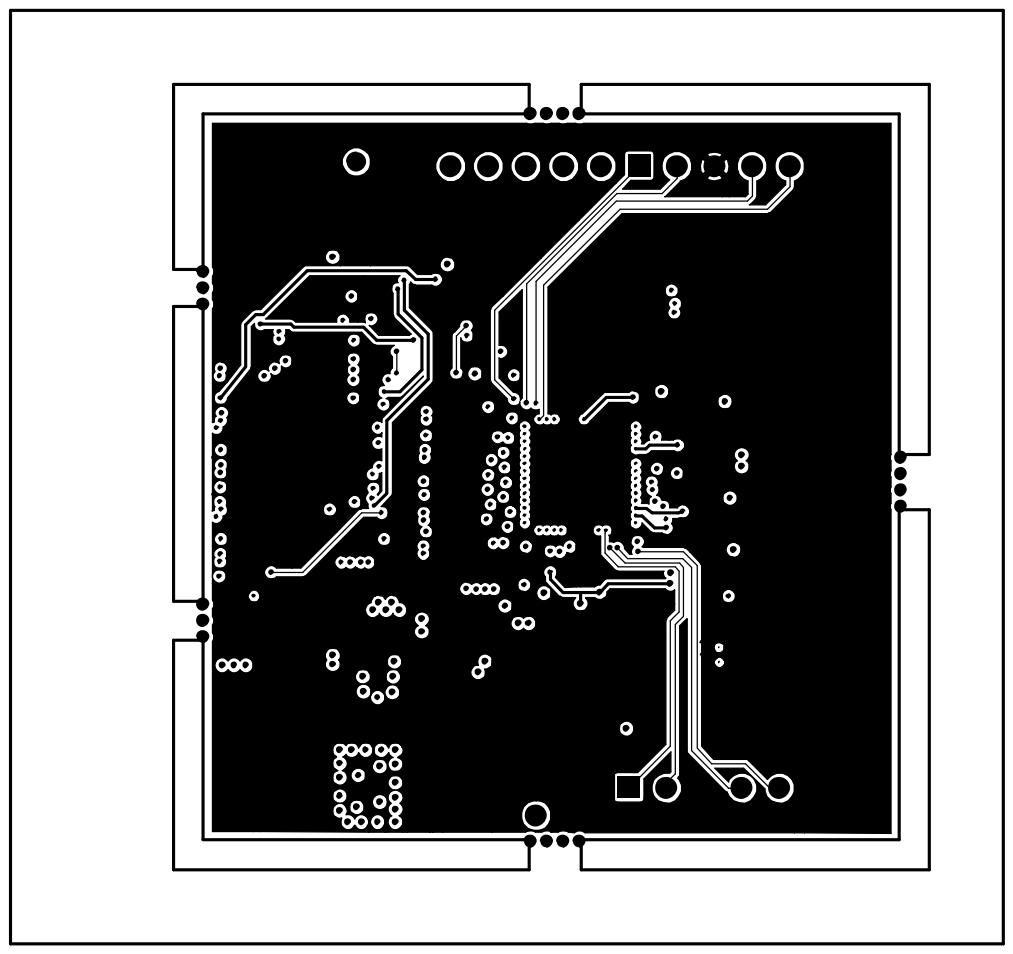
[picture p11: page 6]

MYRIAD_RF-Inner_Analog_Signal.gbr Scale=1.00 Thu Mar 06 18:58:20 2014

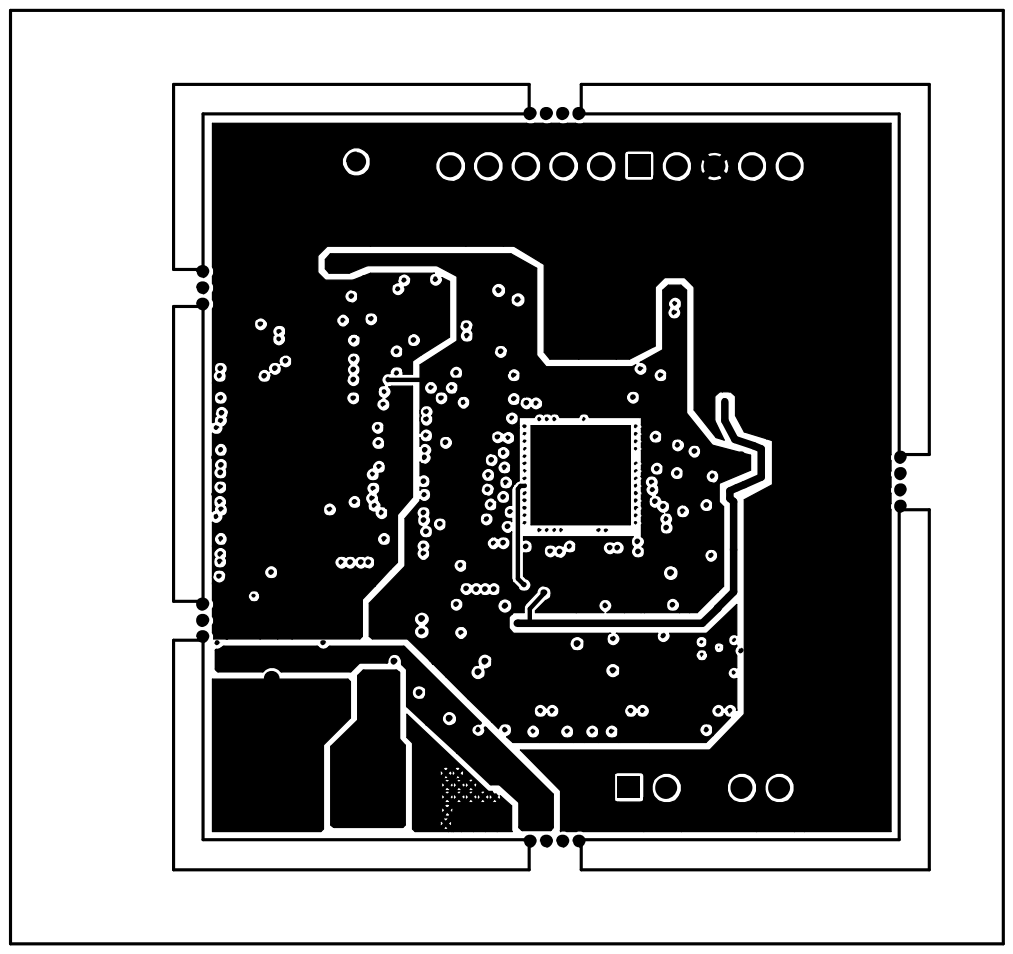
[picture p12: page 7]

MYRIAD_RF-Inner_Power.gbr Scale=1.00 Thu Mar 06 18:58:20 2014

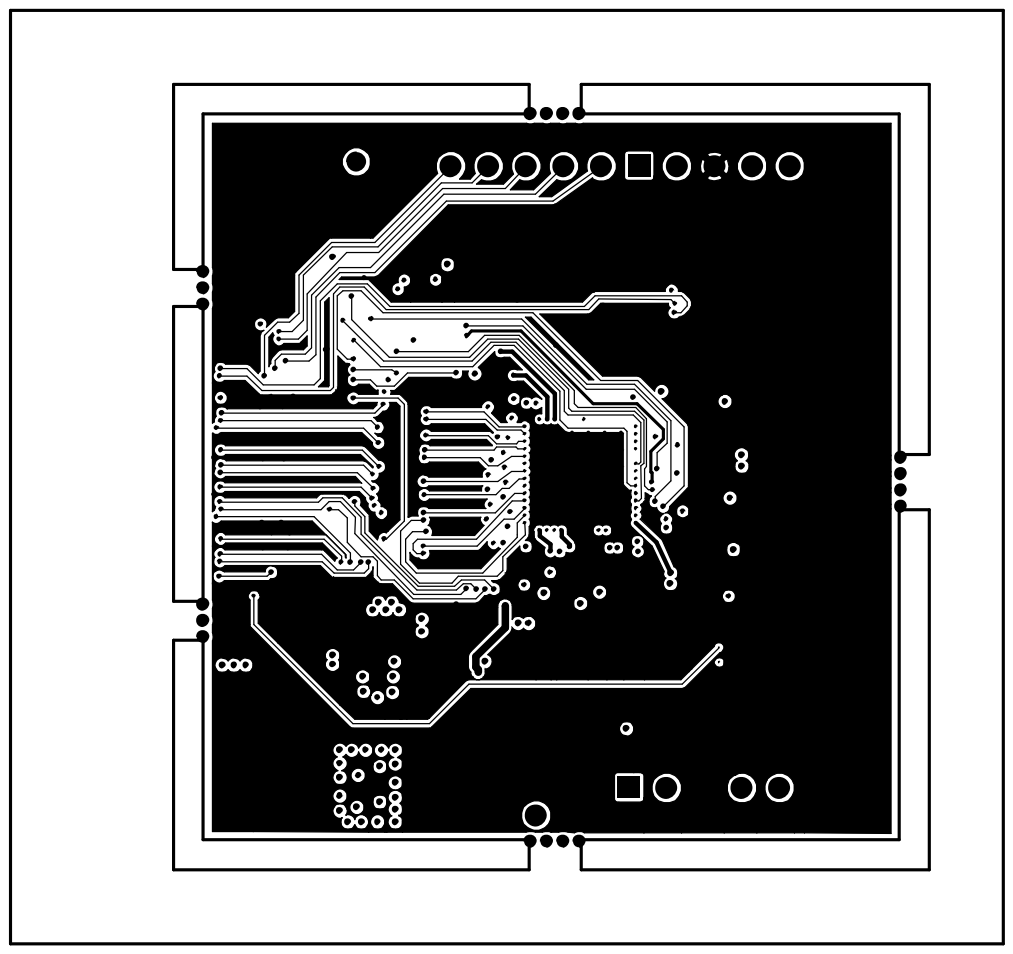
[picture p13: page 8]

MYRIAD_RF-Inner_Digital_Signal.gbr Scale=1.00 Thu Mar 06 18:58:20 2014

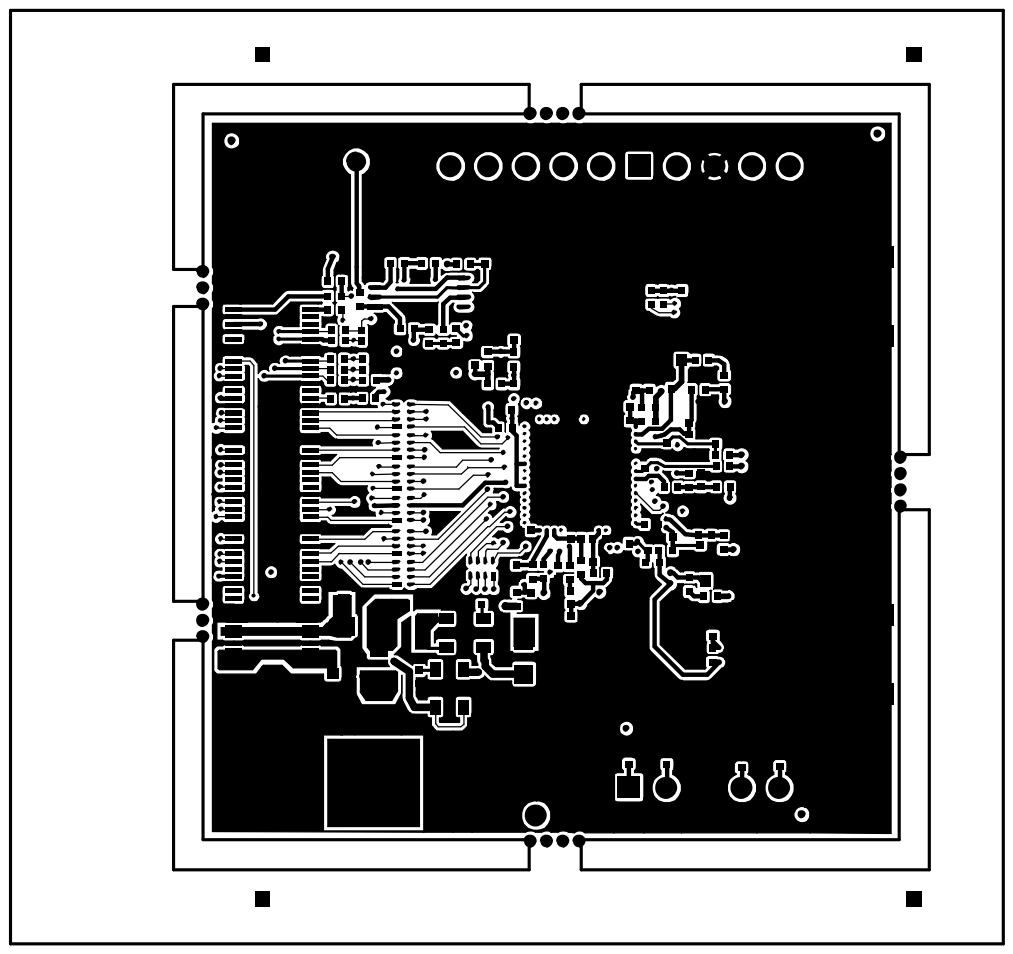
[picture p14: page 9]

MYRIAD_RF-Back.gbl Scale=1.00 Thu Mar 06 18:58:20 2014

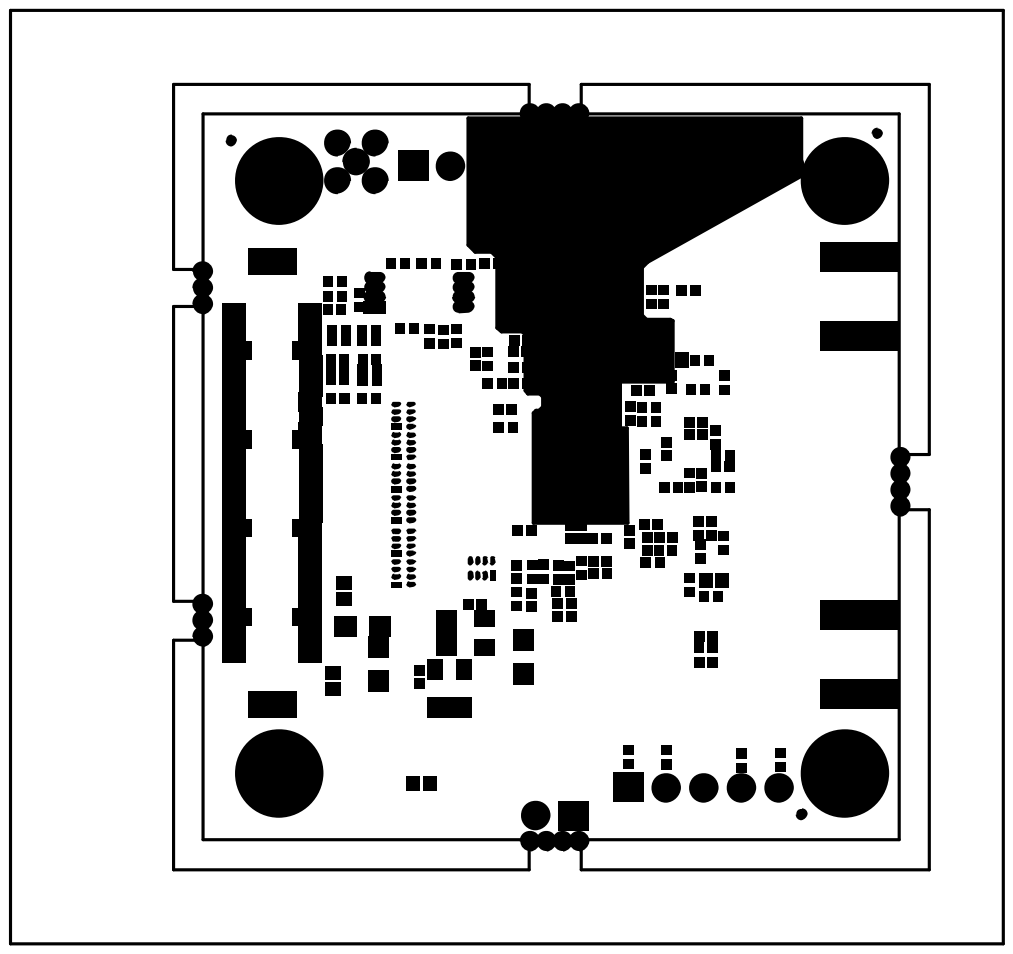
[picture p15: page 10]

MYRIAD_RF-B_Mask.gbs Scale=1.00 Thu Mar 06 18:58:20 2014


MYRIAD_RF-B_SilkS.gbo Scale=1.00 Thu Mar 06 18:58:20 2014


MYRIAD_RF-B_Paste.gbp Scale=1.00 Thu Mar 06 18:58:20 2014


MYRIAD_RF-Edge_Cuts.gbr Scale=1.00 Thu Mar 06 18:58:20 2014


MYRIAD_RF-Dwgs_User.gbr Scale=1.00 Thu Mar 06 18:58:20 2014












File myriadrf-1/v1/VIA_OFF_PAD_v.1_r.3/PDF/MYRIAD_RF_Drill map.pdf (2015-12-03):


MYRIAD_RF-drl_map.pho Scale=1.00 Mon Mar 03 21:43:43 2014


MYRIAD_RF.drl Scale=1.00 Mon Mar 03 21:43:43 2014

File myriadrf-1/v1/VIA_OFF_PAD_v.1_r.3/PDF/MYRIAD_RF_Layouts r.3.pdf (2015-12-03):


MYRIAD_RF-F_Paste.gtp Scale=1.00 Mon Mar 03 21:41:49 2014


MYRIAD_RF-F_SilkS.gto Scale=1.00 Mon Mar 03 21:41:49 2014


MYRIAD_RF-F_Mask.gts Scale=1.00 Mon Mar 03 21:41:49 2014


MYRIAD_RF-Front.gtl Scale=1.00 Mon Mar 03 21:41:49 2014


MYRIAD_RF-Inner_GND.gbr Scale=1.00 Mon Mar 03 21:41:49 2014


MYRIAD_RF-Inner_Analog_Signal.gbr Scale=1.00 Mon Mar 03 21:41:49 2014


MYRIAD_RF-Inner_Power.gbr Scale=1.00 Mon Mar 03 21:41:49 2014


MYRIAD_RF-Inner_Digital_Signal.gbr Scale=1.00 Mon Mar 03 21:41:49 2014


MYRIAD_RF-Back.gbl Scale=1.00 Mon Mar 03 21:41:49 2014


MYRIAD_RF-B_Mask.gbs Scale=1.00 Mon Mar 03 21:41:49 2014


MYRIAD_RF-B_SilkS.gbo Scale=1.00 Mon Mar 03 21:41:49 2014


MYRIAD_RF-B_Paste.gbp Scale=1.00 Mon Mar 03 21:41:49 2014

MYRIAD_RF-Edge_Cuts.gbr Scale=1.00 Mon Mar 03 21:41:49 2014

MYRIAD_RF-Dwgs_User.gbr Scale=1.00 Mon Mar 03 21:41:49 2014


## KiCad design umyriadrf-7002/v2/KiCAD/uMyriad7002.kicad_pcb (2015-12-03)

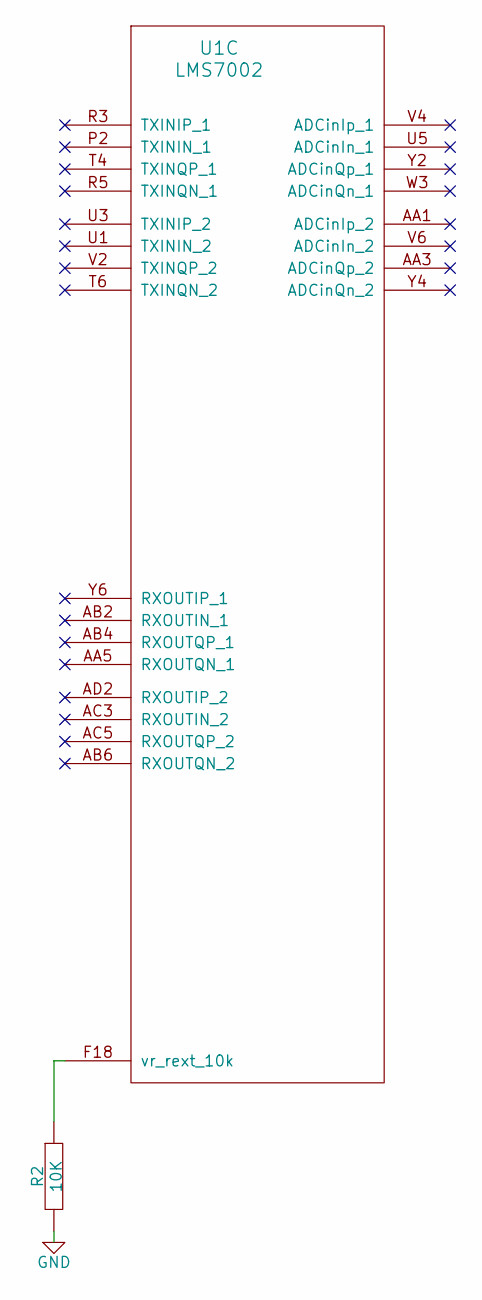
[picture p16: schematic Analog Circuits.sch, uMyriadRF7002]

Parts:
R2: 10K_0402; SMD0402; Manufacturer Part Number RMCF0402FT10K0
U1: LMS7002; aQFN-261

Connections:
GND: R2.2; also elsewhere on the board
unnamed: R2.1, U1.F18 (vr_rext_10k)

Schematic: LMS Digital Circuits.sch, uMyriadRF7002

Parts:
C13, C14, C15: 1UF_0402; SMD0402; Manufacturer Part Number CC0402ZRY5V5BB105
C22: 10PF_0402; SMD0402; Manufacturer Part Number CC0402JRNPO9BN100
J1: 100-PIN_CONNECTOR_3MMHEIGHT; 100-PIN_CONNECTOR; Manufacturer Part Number DF40HC(3.0)-100DS-0.4V(58)
R1, R11, R19, R20, R21, R22, R24: 10K_0402; SMD0402; Manufacturer Part Number RMCF0402FT10K0
R25, R26, R27, R28: 47R_0402; SMD0402; Manufacturer Part Number RC0402FR-0747RL
R29, R39: 2K2_0402; SMD0402; Manufacturer Part Number RC0402FR-072K2L
U1: LMS7002; aQFN-261
U6: 24FC512; 8-TSSOP; Manufacturer Part Number 24FC512-I/ST
U8: 24FC64F; 8-TSSOP; Manufacturer Part Number 24FC64F-I/ST

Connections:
+1.8V: J1.21, J1.22, J1.23, J1.24; also elsewhere on the board
+1.25V: J1.83, J1.84, J1.85, J1.86; also elsewhere on the board
+3.3V: C13.1, C14.1, C15.1, J1.17, J1.18, J1.19, J1.20, R11.1, R19.1, R20.1, R22.1, R24.1, R29.1, R39.1, U6.1 (A0), U6.2 (A1), U6.3 (A2), U6.8 (Vcc), U8.8 (Vcc); also elsewhere on the board
DIG_RST: J1.44, R21.2, U1.V30 (DIG_RST)
DIQ1_D0: J1.74, U1.AG31 (DIQ0_1)
DIQ1_D1: J1.76, U1.AF30 (DIQ1_1)
DIQ1_D2: J1.79, U1.AF34 (DIQ2_1)
DIQ1_D3: J1.72, U1.AE31 (DIQ3_1)
DIQ1_D4: J1.70, U1.AD30 (DIQ4_1)
DIQ1_D5: J1.78, U1.AC29 (DIQ5_1)
DIQ1_D6: J1.77, U1.AE33 (DIQ6_1)
DIQ1_D7: J1.75, U1.AD32 (DIQ7_1)
DIQ1_D8: J1.68, U1.AC31 (DIQ8_1)
DIQ1_D9: J1.73, U1.AC33 (DIQ9_1)
DIQ1_D10: J1.80, U1.AB30 (DIQ10_1)
DIQ1_D11: J1.66, U1.AB32 (DIQ11_1)
DIQ2_D0: J1.52, U1.H30 (DIQ0_2)
DIQ2_D1: J1.49, U1.J31 (DIQ1_2)
DIQ2_D2: J1.50, U1.K30 (DIQ2_2)
DIQ2_D3: J1.51, U1.K32 (DIQ3_2)
DIQ2_D4: J1.56, U1.L31 (DIQ4_2)
DIQ2_D5: J1.54, U1.K34 (DIQ5_2)
DIQ2_D6: J1.58, U1.M30 (DIQ6_2)
DIQ2_D7: J1.53, U1.M32 (DIQ7_2)
DIQ2_D8: J1.60, U1.N31 (DIQ8_2)
DIQ2_D9: J1.55, U1.N33 (DIQ9_2)
DIQ2_D10: J1.64, U1.P30 (DIQ10_2)
DIQ2_D11: J1.62, U1.P32 (DIQ11_2)
ENABLE_IQSEL1: J1.67, U1.Y32 (IQSEL_Enable_1)
ENABLE_IQSEL2: J1.59, U1.R33 (IQSEL_Enable_2)
FCLK1: J1.69, U1.AA33 (FCLK1)
FCLK2: J1.61, U1.R29 (FCLK_2)
FPGA_LMS_CS: J1.38, R25.2
FPGA_SPI_MISO: J1.37, R28.2
FPGA_SPI_MOSI: J1.36, R27.2
FPGA_SPI_SCK: J1.40, R26.2
GND: C13.2, C14.2, C15.2, C22.2, J1.1, J1.2, J1.3, J1.4, J1.5, J1.6, J1.7, J1.8, J1.9, J1.10, J1.15, J1.16, J1.25, J1.26, J1.27, J1.28, J1.29, J1.30, J1.31, J1.32, J1.33, J1.34, J1.81, J1.82, J1.87, J1.88, J1.90, J1.91, J1.92, J1.93, J1.94, J1.95, J1.96, J1.97, J1.98, J1.99, J1.100, R1.1, R21.1, U6.4 (Vss), U6.7 (WP), U8.1 (A0), U8.2 (A1), U8.3 (A2), U8.4 (Vss), U8.7 (WP); also elsewhere on the board
GPIOn: J1.43; also elsewhere on the board
GPIOp: J1.41; also elsewhere on the board
G_PWR_DWN: J1.46, R24.2, U1.U33 (G_PWR_DWN)
MCLK1: J1.71, U1.AB34 (MCLK1)
MCLK2: J1.57, U1.P34 (MCLK_2)
unnamed: R25.1, U1.D28 (SEN)
unnamed: R28.1, U1.F28 (SDO)
unnamed: R27.1, U1.F30 (SDIO)
unnamed: C22.1, R26.1, U1.C29 (SCLK)
unnamed: R29.2, U1.D26 (SDA), U6.5 (SDA), U8.5 (SDA)
unnamed: R39.2, U1.C27 (SCL), U6.6 (SCL), U8.6 (SCL)
RESET: J1.42, R22.2, U1.E27 (RESET)
RXPLL_CLK: J1.89, U1.AM24 (RxPLL_CLK)
RX_EN: J1.47, R11.2, U1.V34 (RX_EN)
TXNRX1: J1.65, R19.2, U1.V32 (TXNRX1)
TXNRX2: J1.63, R1.2, U1.U31 (TXNRX2)
TXPLL_CLK: J1.35, U1.E5 (TxPLL_CLK)
TX_EN: J1.48, R20.2, U1.U29 (TX_EN)

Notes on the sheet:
+5V

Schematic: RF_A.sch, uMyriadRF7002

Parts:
C1, C2, C16, C220, C221: 100NF_0402; SMD0402; Manufacturer Part Number CC0402ZRY5V7BB104
C3, C7, C32: 1PF_0402; SMD0402; Manufacturer Part Number C1005C0G1H010B050BA
C6: 0.5PF_0402_NF; SMD0402; Manufacturer Part Number CC0402CRNPO9BNR50
C9, C10: 4.7PF_0402; SMD0402; Manufacturer Part Number GRM1555C1H4R7BA01D
C17, C222: 22PF_0402; SMD0402; Manufacturer Part Number CC0402JRNPO9BN220
C33, C218, C219, C223: 100PF_0402; SMD0402; Manufacturer Part Number CC0402JRNPO9BN101
EK1: SHIELD_30X25MM; shield_30x25mm
L3, L9: 12NH_0402_NF; IND_0402; Manufacturer Part Number 0402HP-12NX_LU
L4: 3.9NH_0402; IND_0402; Manufacturer Part Number 0402HP-3N9XGLU
L7, L8: 8.2NH_0402; IND_0402; Manufacturer Part Number 0402HP-8N2XJLU
R9, R12: 0R_0805; SM0805; Manufacturer Part Number RC0805JR-070RL
R44: 10K_0402; SMD0402; Manufacturer Part Number RMCF0402FT10K0
T1, T2: TR_TCM1-63AX+; TCM1-63AX+; Manufacturer Part Number TCM1-63AX+
T5: TR_TC1; TC1-1-13MA+; Manufacturer Part Number TC1-1-13MA+
U1: LMS7002; aQFN-261; Manufacturer Part Number LMS7002M
U7: PE4245; 6-DFN_PE4245; Manufacturer Part Number 4245-52
X1, X3: U.FL; Manufacturer Part Number 0734120110

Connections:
+1.8V: C1.1, C2.1, R9.1, R12.1; also elsewhere on the board
+3.3V: C16.1, C17.1, C221.1, C222.1, L9.1, R44.2, U7.4 (Vdd3V); also elsewhere on the board
GND: C1.2, C2.2, C16.2, C17.2, C220.2, C221.2, C222.2, EK1.1, T1.1, T1.2, T1.5, T2.1, T2.2, T2.5, T5.2, T5.4, T5.5, U1.AK12 (RF_gnd), U1.AL13 (RF_gnd), U7.2 (GND), X1.2 (GND), X3.2 (GND); also elsewhere on the board
GPIOp: C220.1, R44.1, U7.5 (CTRL); also elsewhere on the board
unnamed: C218.2, U7.3 (RF1)
unnamed: C223.1, U7.6 (RFC)
unnamed: C218.1, T5.6
unnamed: C3.2, C7.1, T1.4
unnamed: C7.2, C32.2, T1.6
unnamed: C219.1, T2.3
unnamed: C219.2, U7.1 (RF2)
unnamed: C223.2, L9.2, X1.1 (RF)
unnamed: L7.1, R9.2
unnamed: L8.1, R12.2
unnamed: C33.1, T1.3
unnamed: C9.1, L3.1, U1.AK14 (RXRF1_p_h)
unnamed: C10.1, L3.2, U1.AJ15 (RXRF1_n_h)
unnamed: C9.2, L4.1, T2.4
unnamed: C10.2, L4.2, T2.6
unnamed: C6.2, C32.1, L8.2, U1.A7 (TXRF1_1n)
unnamed: C33.2, X3.1 (RF)
unnamed: C3.1, C6.1, L7.2, U1.B8 (TXRF1_1p)
unnamed: T5.3, U1.AM12 (RXRF1_n_l)
unnamed: T5.1, U1.AN11 (RXRF1_p_l)

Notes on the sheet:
TXOUT_A
GPIO 0 - RF1 1 - RF2
RXIN_A

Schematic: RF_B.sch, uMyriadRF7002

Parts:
C11, C12: 4.7PF_0402; SMD0402; Manufacturer Part Number GRM1555C1H4R7BA01D
C18, C38, C39, C233, C234: 100NF_0402; SMD0402; Manufacturer Part Number CC0402ZRY5V7BB104
C19, C235: 22PF_0402; SMD0402; Manufacturer Part Number CC0402JRNPO9BN220
C40, C42, C43: 1PF_0402; SMD0402; Manufacturer Part Number C1005C0G1H010B050BA
C41: 0.5PF_0402_NF; SMD0402; Manufacturer Part Number CC0402CRNPO9BNR50
C45, C231, C232, C236: 100PF_0402; SMD0402; Manufacturer Part Number CC0402JRNPO9BN101
EK2: SHIELD_30X25MM; shield_30x25mm
L5, L14: 12NH_0402_NF; IND_0402; Manufacturer Part Number 0402HP-12NX_LU
L6: 3.9NH_0402; IND_0402; Manufacturer Part Number 0402HP-3N9XGLU
L12, L13: 8.2NH_0402; IND_0402; Manufacturer Part Number 0402HP-8N2XJLU
R13, R14: 0R_0805; SM0805; Manufacturer Part Number RC0805JR-070RL
R45: 10K_0402; SMD0402; Manufacturer Part Number RMCF0402FT10K0
T3, T4: TR_TCM1-63AX+; TCM1-63AX+; Manufacturer Part Number TCM1-63AX+
T6: TR_TC1; TC1-1-13MA+; Manufacturer Part Number TC1-1-13MA+
U1: LMS7002; aQFN-261
U9: PE4245; 6-DFN_PE4245; Manufacturer Part Number 4245-52
X2, X4: U.FL; Manufacturer Part Number 0734120110

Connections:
+1.8V: C38.1, C39.1, R13.1, R14.1; also elsewhere on the board
+3.3V: C18.1, C19.1, C234.1, C235.1, L14.1, U9.4 (Vdd3V); also elsewhere on the board
GND: C18.2, C19.2, C38.2, C39.2, C233.2, C234.2, C235.2, EK2.1, R45.2, T3.1, T3.2, T3.5, T4.1, T4.2, T4.5, T6.2, T6.4, T6.5, U1.AJ7 (RF_gnd), U1.AJ9 (RF_gnd), U9.2 (GND), X2.2 (GND), X4.2 (GND); also elsewhere on the board
GPIOn: C233.1, R45.1, U9.5 (CTRL); also elsewhere on the board
unnamed: C231.1, T6.6
unnamed: C231.2, U9.1 (RF2)
unnamed: C232.2, U9.3 (RF1)
unnamed: T6.3, U1.AN5 (RXRF2_l_p)
unnamed: C236.1, U9.6 (RFC)
unnamed: C236.2, L14.2, X2.1 (RF)
unnamed: C12.2, L6.2, T4.4
unnamed: C42.2, C43.2, T3.6
unnamed: C45.1, T3.3
unnamed: C232.1, T4.3
unnamed: C11.1, L5.1, U1.AN7 (RXRF2_h_p)
unnamed: C12.1, L5.2, U1.AM8 (RXRF2_h_n)
unnamed: C11.2, L6.1, T4.6
unnamed: T6.1, U1.AP6 (RXRF2_l_n)
unnamed: L13.1, R14.2
unnamed: L12.1, R13.2
unnamed: C41.2, C43.1, L13.2, U1.C11 (TXRF1_2n)
unnamed: C45.2, X4.1 (RF)
unnamed: C40.2, C42.1, T3.4
unnamed: C40.1, C41.1, L12.2, U1.B12 (TXRF1_2p)

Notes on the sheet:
TXOUT_B
GPIO 0 - RF1 1 - RF2
RXIN_B

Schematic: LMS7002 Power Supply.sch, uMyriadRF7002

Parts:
C4, C8: 1UF_0402; SMD0402; Manufacturer Part Number CC0402ZRY5V5BB105
C35, C47, C50, C51, C52, C53, C54, C55, C56, C57, C58, C59, C60, C61, C62, C63, C65, C66, C67, C68, C69, C111, C145, C154, C167, C173, C175, C195, C197, C204, C205, C206, C207, C208, C209, C210, C211, C212, C213, C214, C255, C283, C301, C302, C303, C304: 1UF_0201; SM0201; Manufacturer Part Number C0603X5R0J105M030BC
FB1, FB2, FB3, FB4, FB5, FB6, FB7, FB8, FB9, FB10, FB11, FB12, FB13, FB14, FB15, FB16, FB17, FB18, FB19, FB22, FB24: FB_0201; SM0201; Manufacturer Part Number BK0603TS601-T
FB23, FB25: FB_0201_NF; SM0201; Manufacturer Part Number BK0603TS601-T
FD1, FD2, FD3, FD4: FIDUCIAL; Pad
LD1: LED; LED_0603; Manufacturer Part Number LG Q971-KN-1
R3, R4: 0.22R_0402; SMD0402; Manufacturer Part Number RL0402FR-070R22L
R5, R6, R40, R43: 0R_0201; SMD0201; Manufacturer Part Number MCR006YRTJ000
R7, R17, R23, R33, R41, R42: 10R_0201; SMD0201; Manufacturer Part Number RC0201JR-0710RP
R8: 0R_0402; SMD0402; Manufacturer Part Number RC0402JR-070RL
R10: 470R_0402; SMD0402; Manufacturer Part Number ERA-2AED471X
U1: LMS7002; aQFN-261
U2: LD39115J14R; 4-UFBGA; Manufacturer Part Number LD39115J14R

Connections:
+1.4V: FB5.2, FB15.2, FB18.2, FB23.2, FB25.1, R8.1
+1.8V: FB3.2, FB6.1, FB7.2, FB14.1, FB16.2, FB17.1, R5.2; also elsewhere on the board
+1.25V: C60.2, C63.1, C66.2, C69.1, C173.1, C175.2, FB1.1, FB2.2, FB4.2, FB8.2, FB9.1, FB10.2, FB11.2, FB12.1, FB13.2, FB19.1, FB22.1, FB24.1, R3.2, R7.2, R17.1, R23.2, R33.1, R41.1, R42.2; also elsewhere on the board
+3.3V: C4.1, R4.1, R10.1, U2.A2 (EN), U2.B2 (IN); also elsewhere on the board
/LMS7002 Power Supply/RF Power 1: C58.1, C302.1, FB2.1, R6.1, R40.1, U1.B16 (VDD_TPAD_TRF), U1.F8 (VDD_TLOBUF_TRF), U1.K6 (VDD12_VCO_SXT)
/LMS7002 Power Supply/RF Power 2: C283.2, FB22.2, U1.AN23 (VDD12_VCO_SXR)
GND: C4.2, C8.2, C35.1, C47.1, C50.1, C51.1, C52.1, C53.1, C54.1, C55.1, C56.2, C57.1, C58.2, C59.2, C60.1, C61.1, C62.2, C63.2, C65.2, C66.1, C67.1, C68.2, C69.2, C111.2, C145.1, C154.2, C167.2, C173.2, C175.1, C195.1, C197.2, C204.1, C205.2, C206.2, C207.1, C208.2, C209.1, C210.2, C211.2, C212.1, C213.2, C214.1, C255.2, C283.1, C301.2, C302.2, C303.2, C304.1, LD1.2 (K), U1.AA31 (DIGPRGND1), U1.AF32 (DIGPRGND2), U1.AG29 (DIGPRGND1), U1.AJ19 (GND_CP_SXR), U1.AK20 (GND_DIV_SXR), U1.AL23 (GND_VCO_SXR), U1.AM22 (DGND_SXR), U1.AN25 (GND_RXBUF), U1.B18 (DGND_CGEN), U1.B20 (GND_CP_CGEN), U1.C7 (GND_TLOBUF_TRF), U1.C23 (GND_DIG), U1.D20 (GND_DIV_CGEN), U1.E25 (GND_SPI_BUF), U1.F6 (GND_TXBUF), U1.G31 (DIGPRGND2), U1.GND (GND_TPAD_TRF), U1.H2 (GND_VCO_SXT), U1.J33 (DIGPRGND1), U1.K4 (GND_CP_SXT), U1.L3 (GND_DIV_SXT), U1.N3 (DGND_SXT), U1.T30 (DIGPRGND1), U1.W29 (DIGPRGND1), U1.Y30 (DIGPRGND2), U2.A1 (GND); also elsewhere on the board
unnamed: C167.1, R41.2, U1.AL19 (VDD_CP_SXR)
unnamed: C197.1, FB8.1, U1.AM20 (VDD_DIV_SXR)
unnamed: C213.1, FB18.1, U1.AD4 (VDD14_RBB)
unnamed: C62.1, R17.2, U1.A17 (DVDD_CGEN)
unnamed: C154.1, FB7.1, U1.AM18 (VDD18_SXR)
unnamed: C205.1, FB10.1, FB23.1, U1.AN17 (VDD_MXLOBUF_RFE)
unnamed: C208.1, FB13.1, U1.AP26 (VDD12_RXBIF)
unnamed: C211.1, C255.1, FB16.1, U1.AK22 (VDD18_VCO_SXR), U1.AM26 (VDD18_RXBUF)
unnamed: C59.1, C303.1, FB3.1, U1.D16 (VDD18_TRF), U1.E17 (VDD18_BIAS), U1.E21 (VDD18_VCO_CGEN)
unnamed: C111.1, FB5.1, U1.C21 (VDD14_VCO_CGEN)
unnamed: C210.1, FB15.1, U1.AF2 (VDD14_TIA_RFE), U1.AF6 (VDD14_LNA_RFE)
unnamed: C206.1, FB11.1, U1.AJ25 (VDD_AFE)
unnamed: R6.2, U1.D6 (VDDO_TLOBUF_TRF)
unnamed: C65.1, FB4.1, U1.E19 (VDD_DIV_CGEN)
unnamed: C8.1, R8.2, U2.B1 (OUT)
unnamed: LD1.1 (A), R10.2
unnamed: C68.1, R33.2, U1.F20 (VDD_CP_CGEN)
unnamed: C47.2, C53.2, C54.2, C55.2, R4.2, U1.AH30 (DIGPRVDD2), U1.H32 (DIGPRVDD2), U1.T32 (DIGPRVDD2), U1.W31 (DIGPRPOC), U1.W33 (DIGPRVDD2)
unnamed: C212.2, FB17.2, U1.AE3 (VDD18_TIA_RFE), U1.AF4 (VDD18_LDO_RX)
unnamed: C209.2, FB14.2, U1.N1 (VDD18_LDO_TX)
unnamed: C214.2, FB19.2, U1.AD6 (VDD12_TIA_RFE), U1.AG5 (VDD12_LNA_RFE)
unnamed: C56.1, R5.1, U1.D24 (VDD18_DIG)
unnamed: C207.2, FB12.2, U1.G5 (VDD12_TXBUF)
unnamed: C57.2, C304.2, FB1.2, U1.C25 (VDD12_DIG), U1.F24 (VDD_SPI_BUF)
unnamed: C35.2, C50.2, C51.2, C52.2, R3.1, U1.AA29 (DIGPRVDD1), U1.AE29 (DIGPRVDD1), U1.L33 (DIGPRVDD1), U1.R31 (DIGPRVDD1)
unnamed: C301.1, FB24.2, U1.P4 (VDD_TBB)
unnamed: R43.1, U1.K2 (VDDO_DIV_SXT)
unnamed: R40.2, U1.J5 (VDD12O_VCO_SXT)
unnamed: C145.2, FB6.2, U1.G3 (VDD18_VCO_SXT), U1.H6 (VDD18_TXBUF)
unnamed: C67.2, R23.1, U1.M4 (DVDD_SXT)
unnamed: C61.2, R7.1, U1.AL21 (DVDD_SXR)
unnamed: C195.2, R42.1, U1.J3 (VDD_CP_SXT)
unnamed: C204.2, FB9.2, FB25.2, R43.2, U1.L5 (VDD_DIV_SXT)

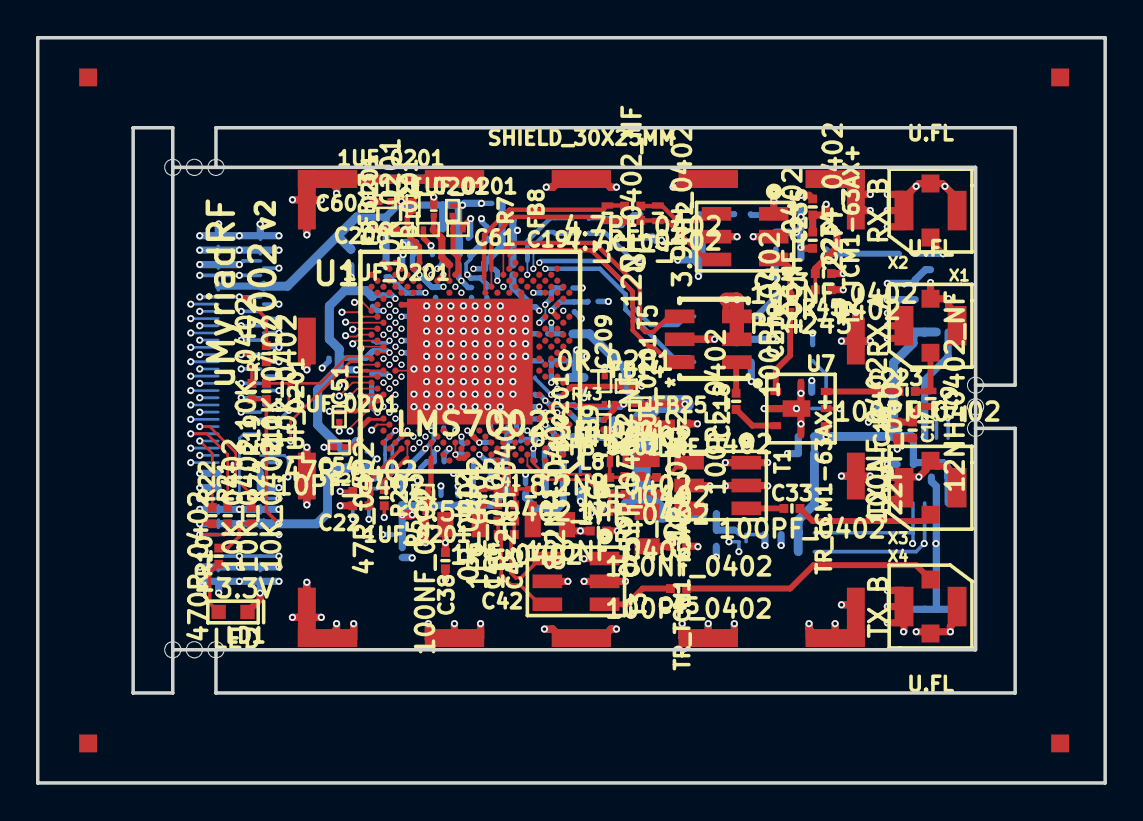
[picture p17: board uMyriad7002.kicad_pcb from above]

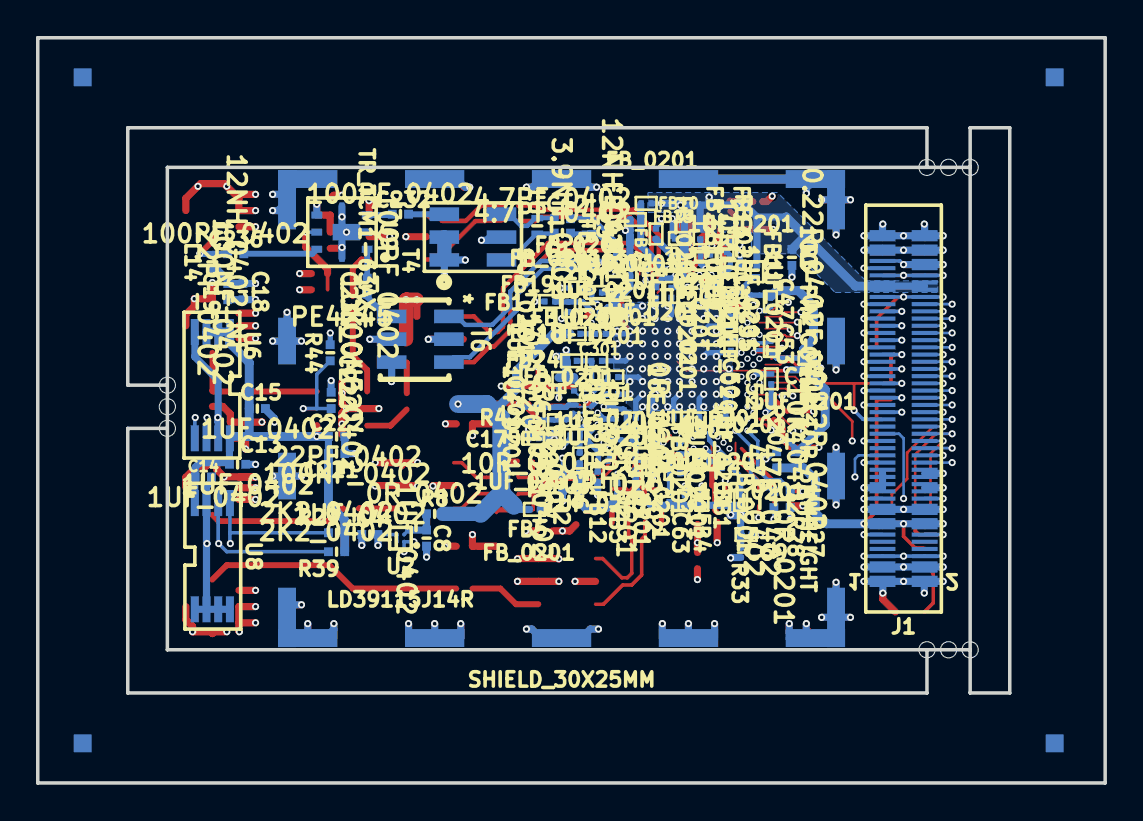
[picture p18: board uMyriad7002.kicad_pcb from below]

Board: 8 copper layers, 59.3 x 41.4 mm, 186 parts (99 on the bottom side), 132 nets.

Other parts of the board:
BreakHole: VAL**; BreakHole
BreakHole#2, BreakHole#3, BreakHole#4, BreakHole#5, BreakHole#6, BreakHole#7, BreakHole#8, BreakHole#9: VAL**; BreakHole

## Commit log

2015-12-03 Added micro form factor LMS6002 and LMS7002 RF module designs
    [Analog Circuits.sch, Clocks, RF FE.sch, Connectors.sch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]
2016-06-17 Added LMS8001 Companion design
    [Clocks.sch, LMS8001_Companion.kicad_pcb, LMS8001_Companion.sch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]
2021-11-10 Update README.md
    https://forum.kicad.info/t/warning-avoid-all-links-to-kicad-pcb-org-use-kicad-org/31521

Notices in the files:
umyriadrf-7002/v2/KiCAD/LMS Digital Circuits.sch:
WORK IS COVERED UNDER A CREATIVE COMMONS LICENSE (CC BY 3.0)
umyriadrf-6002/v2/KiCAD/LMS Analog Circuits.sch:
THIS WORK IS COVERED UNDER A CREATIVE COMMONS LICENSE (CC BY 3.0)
